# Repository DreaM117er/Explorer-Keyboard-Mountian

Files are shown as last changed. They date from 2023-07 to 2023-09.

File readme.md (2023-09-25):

# Explorer Keyboard Mountain 探索者2號（一體式）

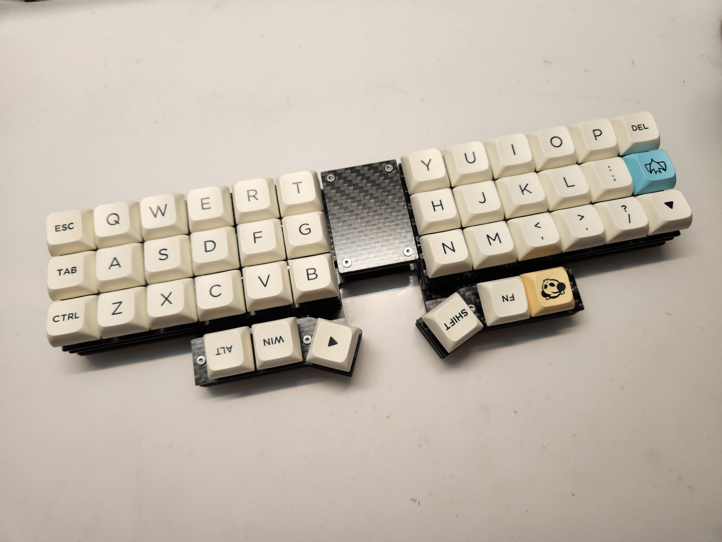
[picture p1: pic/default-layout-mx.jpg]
default-layout-mx
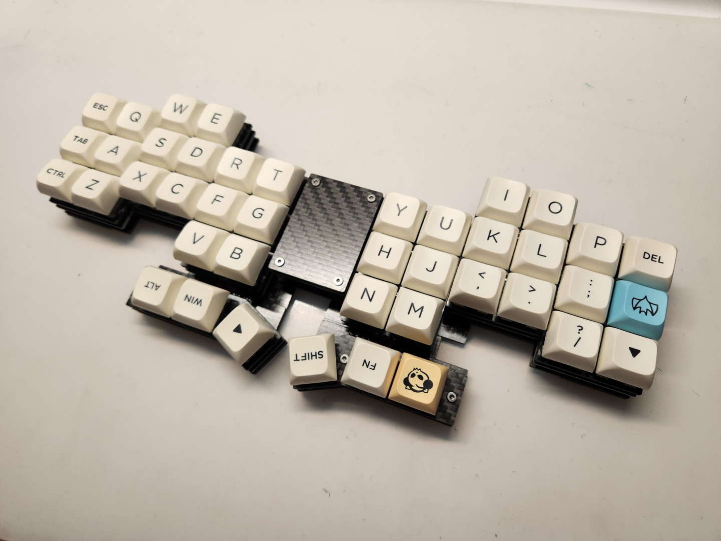
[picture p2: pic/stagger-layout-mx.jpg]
stagger-layout-mx
|||
|--|--|
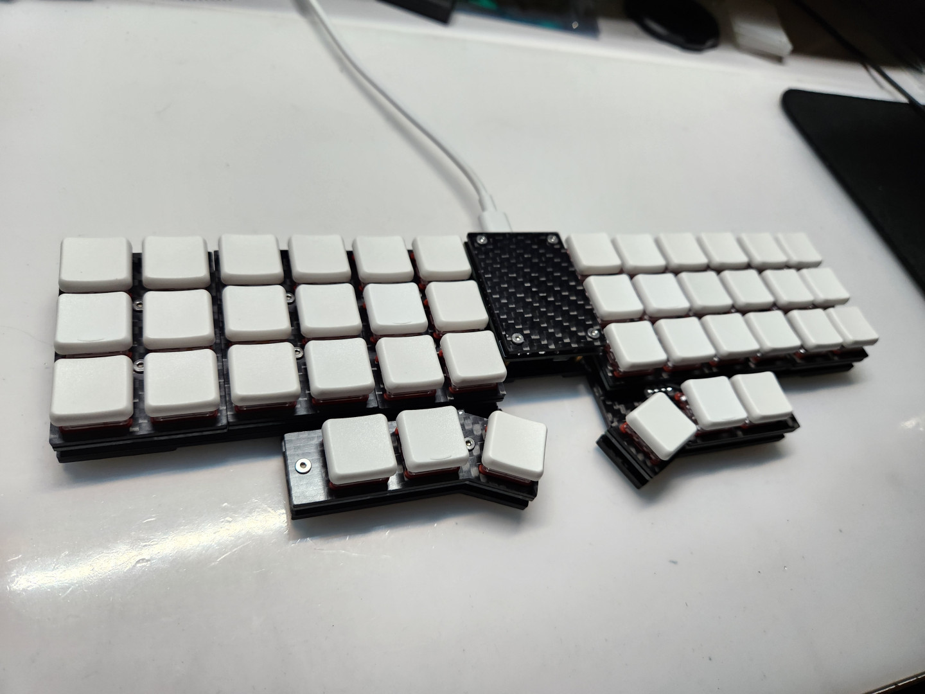
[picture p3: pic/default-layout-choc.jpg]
default-layout-choc
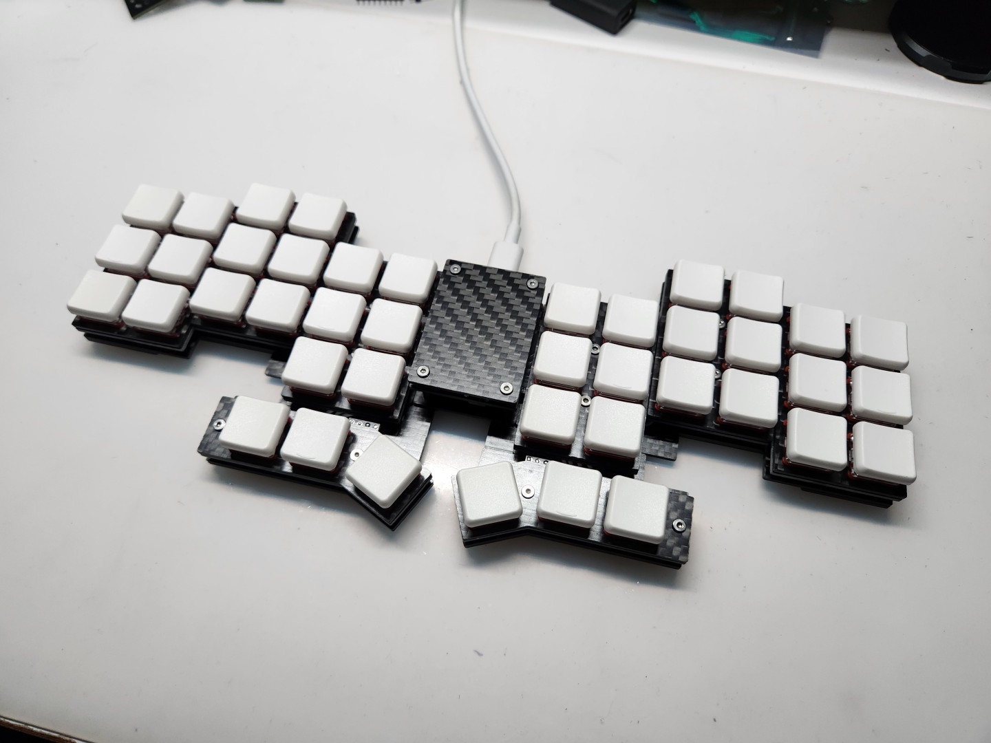
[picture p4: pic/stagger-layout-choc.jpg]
stagger-layout-choc
|||
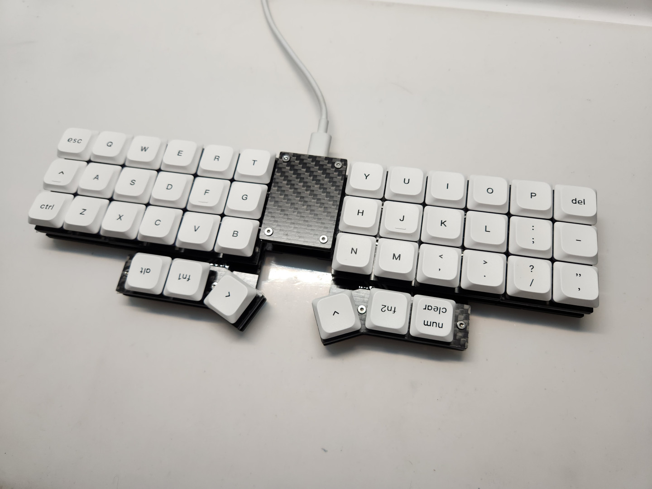
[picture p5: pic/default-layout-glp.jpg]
default-layout-glp
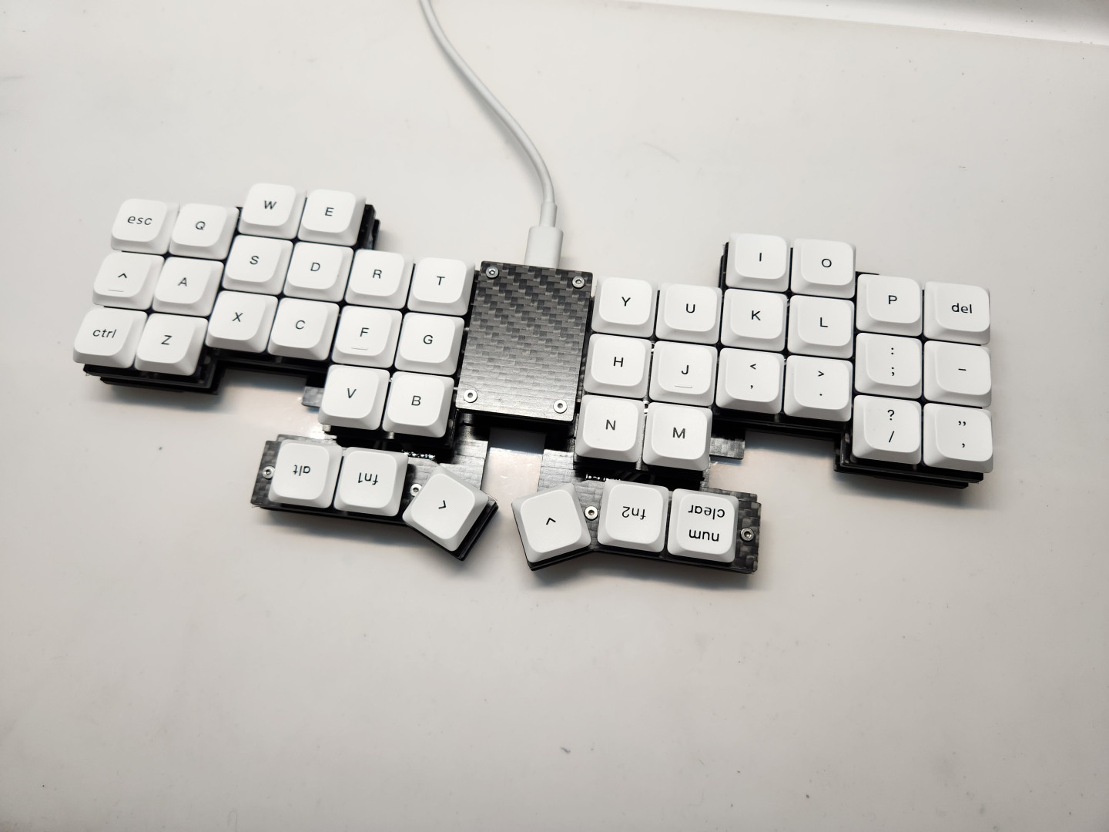
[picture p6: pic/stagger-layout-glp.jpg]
stagger-layout-glp
|||
## 開發者前言

Planck好不好用？這是我在接觸分離式鍵盤之後很多人問我的問題，我可以說它相當地好用，是第一次接觸分離式鍵盤的初心者在使用它之後也非常容易上手，且不論這把直列式鍵盤類型是不是分離式。根據Planck入門的好用程度，首先我製作了一把以Planck為雛形的直列式小鍵盤Plancklite，省去了小指及無名指最難接觸到的左下角、右下角的各3顆按鍵，再將鍵盤從中央分開來成左右兩邊、拇指區向下跟主鍵區位移3mm的設計。

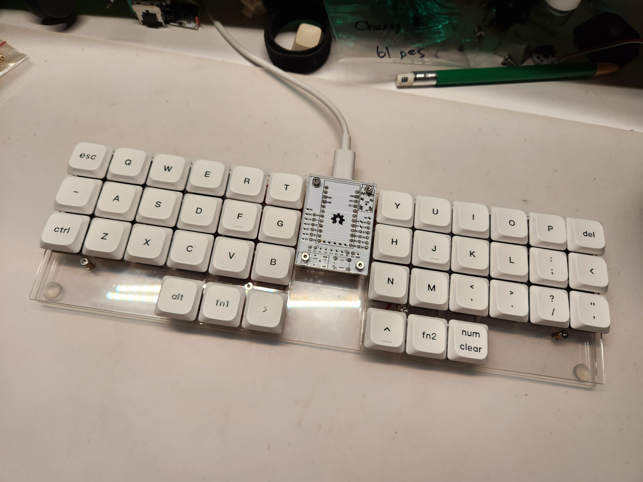
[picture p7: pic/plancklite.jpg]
plancklite


這樣去更動配列的好處其實改善了Planck鍵盤配列的幾個問題：

- 按鍵佈局太緊湊。
- 省去手指正常移動軌跡中根本按不到的按鍵。
- 保留Planck直列式鍵盤的打字手感，甚至更好。
- 可作為分離式鍵盤練習使用。

於是根據這把小鍵盤Plancklite，更進一步構想出這把可以變動配列的探索者2號。

這次的開發跟探索者1號那次不太一樣，開發、構想、設計、命名全靠我一個人，特別在這次的開發上，我特別學習了KiCAD的使用，同時運用Fusion360做鍵盤的3D結構模擬及零件的檔案輸出，能夠這樣開發出自己的鍵盤，真的相當不容易。

至於命名的部分，為什麼叫做Mountian呢？其實探索者2號的命名在1號設計出來沒多久就定下來了，原先它的目標是能夠立起來的設計，在設計過程中逐漸偏離原始構想，後來才想到這個類似七巧板的設計，但原先定下來的命名就繼續沿用了，但它現在的構造其實也蠻符合這個味道。

如果大家對這把鍵盤有興趣的話，不妨嘗試自己做看看：[組裝說明](guide.md)

分離式連結：[Half-Mountain](readme_hm.md)。

## 配列佈局

探索者2號有兩種佈局可以變更，預設佈局為Plancklite的設計，拇指區最外側旋轉25度的設計，在使用上更貼合拇指移動的按鍵軌跡。

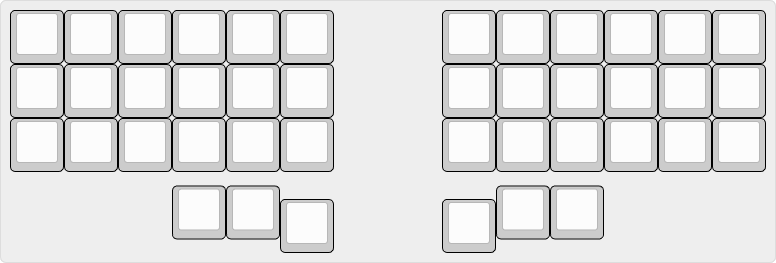
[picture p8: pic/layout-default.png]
Plancklite


在此之上，根據鍵盤結構的變化，可將Plancklite的配列變更為Stagger的配列：

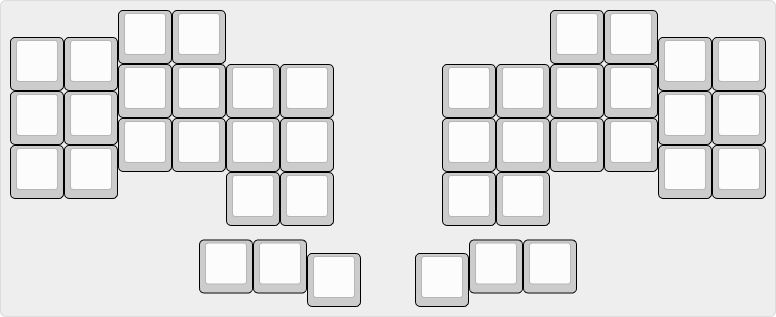
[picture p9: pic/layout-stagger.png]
mountain


## 鍵盤結構

- 根據PCB分為`M（Main）`、`A（A part）`、`B（B part）`、`T（Thumb）`單邊4個部件，合計8張PCB。
- 左右邊代號分別為：`左（L）`、`右（R）`。
- 鍵盤上下結構分為：`Plate（定位板）`、`A（上層底板）`、`B（下層底板）`。
- MCU的部分採用手拉線拓展板安裝（[Handwiring Microboard](https://github.com/DreaM117er/Handwiring-Microboard)）。
- PCB採全焊接設計，可使用`MX`、`Choc v1`、`Choc v2`、`Gateron矮軸`等4款不同腳位、不同類型的鍵軸。
- 可依據需求進行配列的變更，Plancklite及Stagger可選擇。

### PCB視圖

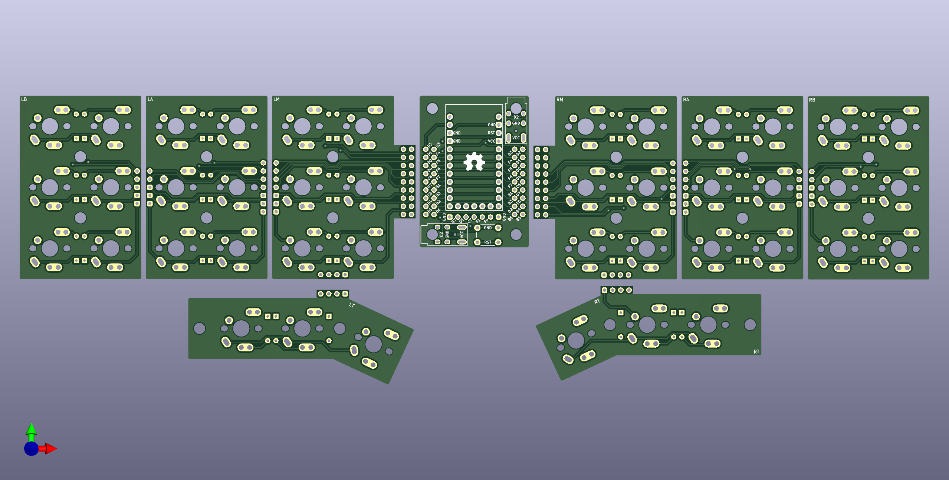
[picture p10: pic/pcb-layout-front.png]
PCB-F
|正面||
|--|--|
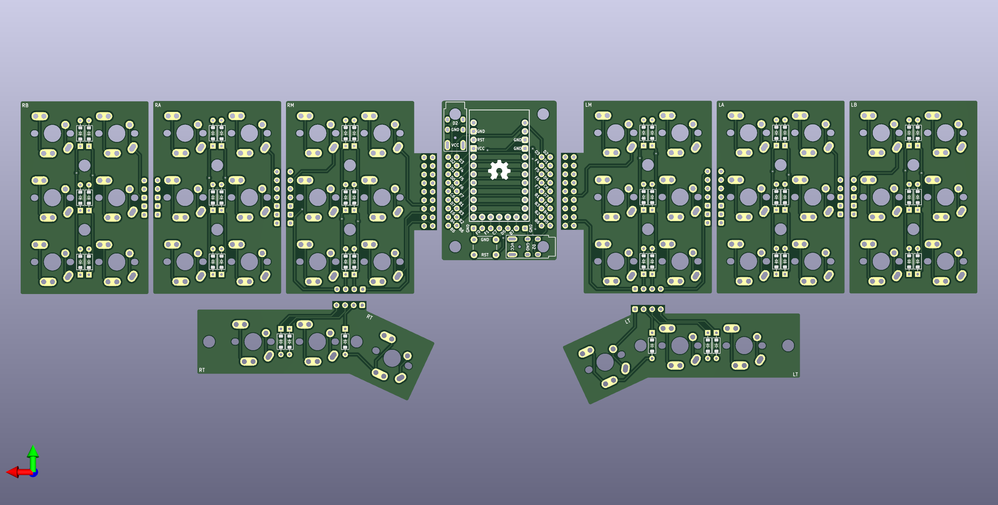
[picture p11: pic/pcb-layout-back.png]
PCB-B
|背面||

### 3D視圖

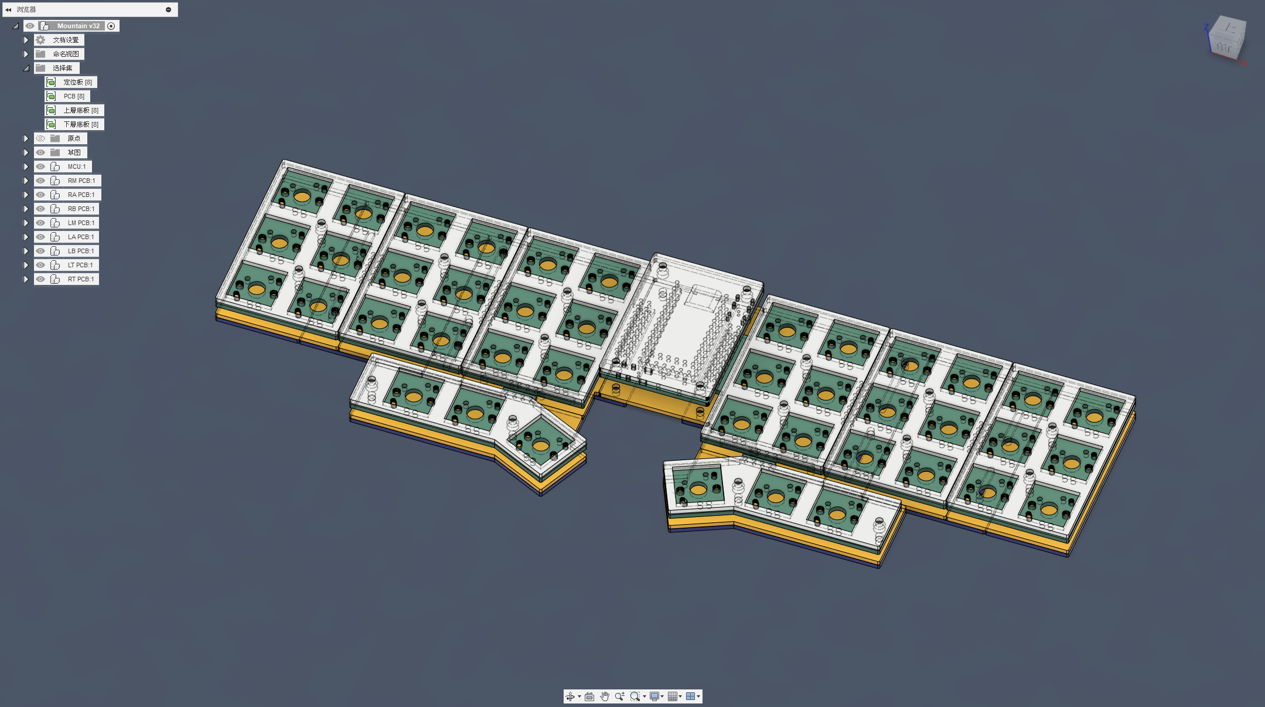
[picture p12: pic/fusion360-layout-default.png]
default
|正面||
|--|--|
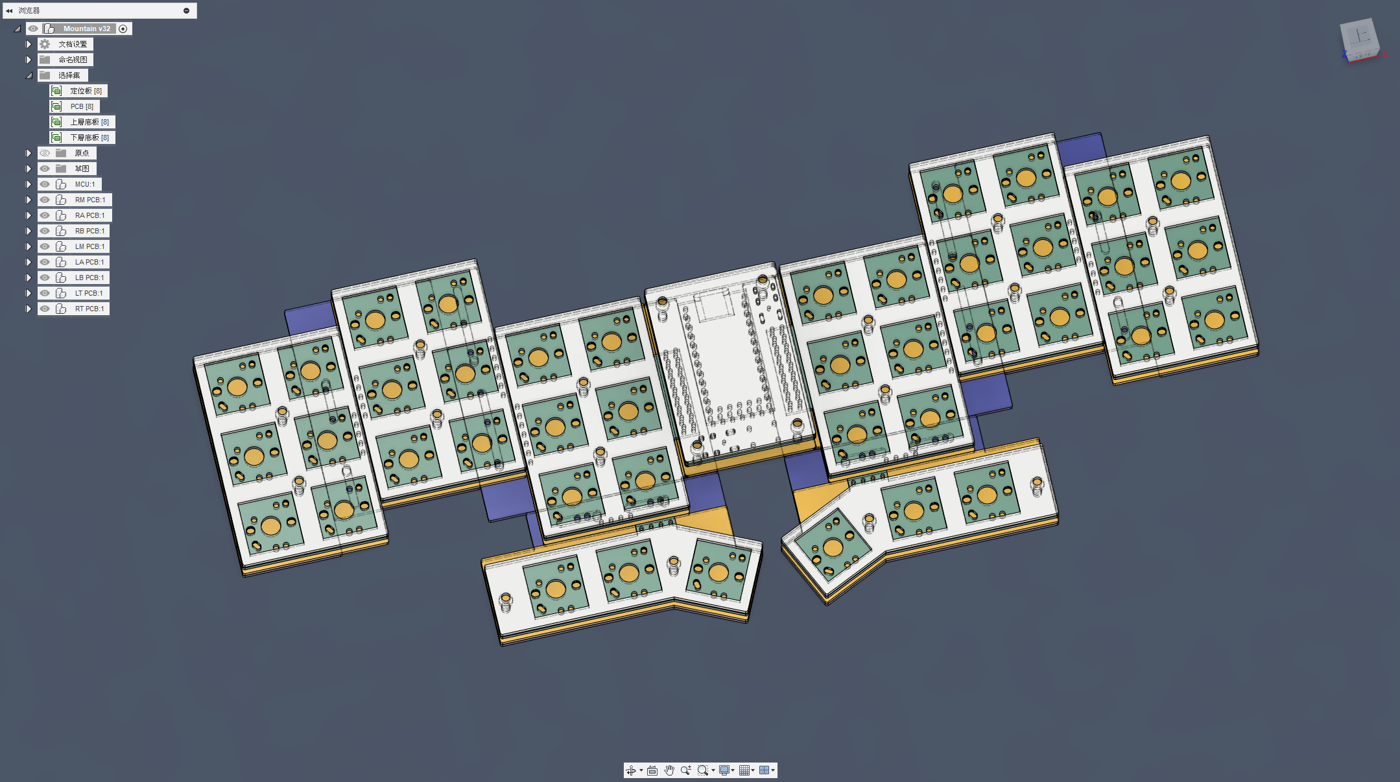
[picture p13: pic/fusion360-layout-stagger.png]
stagger
|背面||

## 參考資料及使用工具

- [凱華電子規格書](https://www.kailh.net/pages/product-datasheet)（`MX`、`Choc v1`、`Choc v2`）。
- [佳特隆電子規格書](https://www.gateron.co/products/gateron-low-profile-mechanical-switch-set)（`Gateron矮軸`）。
- [KiCAD](https://www.kicad.org/) version `7.05`。
- [Autodesk Fusion360](https://www.autodesk.com/products/fusion-360/overview?term=1-YEAR&tab=subscription)。
- [JLCPCB](https://jlcpcb.com/)。
- [鑫帆宇碳纤维用品加工店](https://shop73091441.taobao.com/?spm=a1z10.1-c-s.0.0.3530f19cYKPwZf)。
- [開發日製](log.md)。

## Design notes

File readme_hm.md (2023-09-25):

# Explorer Keyboard Half-Mountain 探索者2號（分離式）

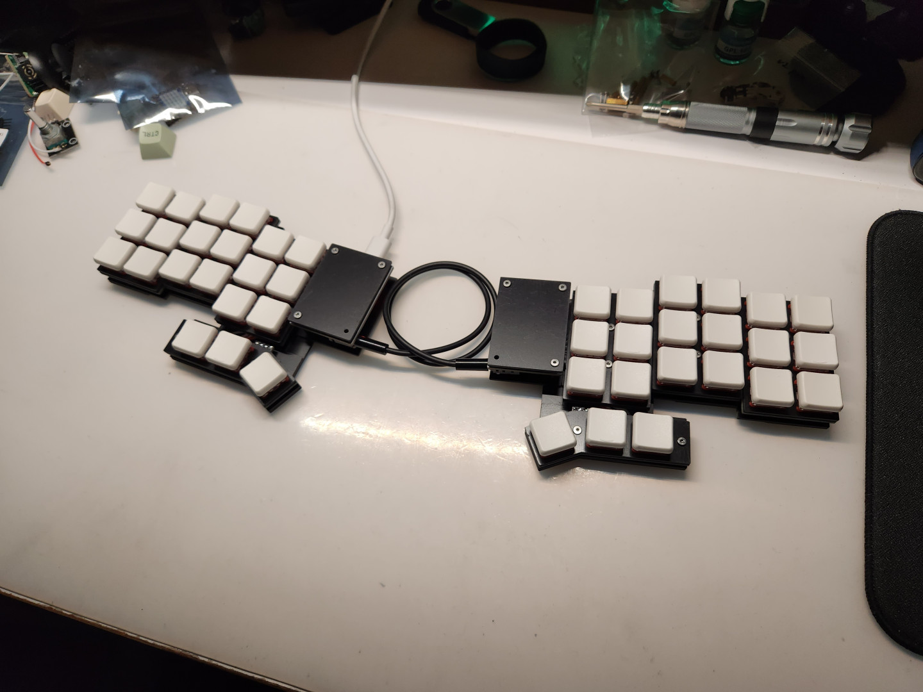
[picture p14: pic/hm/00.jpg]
Half-Mountian


## 開發者前言

探索者2號分離式版是2號本身的進階運用，使用2片的手拉線拓展板進行拓展，將一體式的探索者2號直接從中央切開來，再用分離式鍵盤常見的TRS或TRRS線做左右兩側鍵盤的連接，來滿足不喜歡一體式鍵盤使用者的需求。

由於是分離式版的探索者2號是將鍵盤從中央切開來的原因，很直接地將鍵盤稱之為`半山（Half-Mountain）`。

## 組裝說明

Half-Mountain是在Mountain的基礎上做延伸的分離式鍵盤，詳見以下材料不同處：

|項目|數量|備註|
| -- | -- | -- |
|[手拉線拓展板](https://github.com/DreaM117er/Handwiring-Microboard)（`Handwiring Microboard`）|2片|-|
|`Pro Micro` `5V16M`|2片|同腳位MCU都可|
|MCU保護板（`cover`）|4片|上下及左右|
|`TRRS座`|2個|-|
|`2pin` 輕觸開關|2個||

- 其餘材料都和[Mountain](https://github.com/DreaM117er/Explorer-Keyboard-Mountian/blob/main/guide.md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)一致。

## 組裝步驟

- 請按照步驟先將2片手拉線拓展版安裝完畢：[請點這裡](https://github.com/DreaM117er/Handwiring-Microboard)。

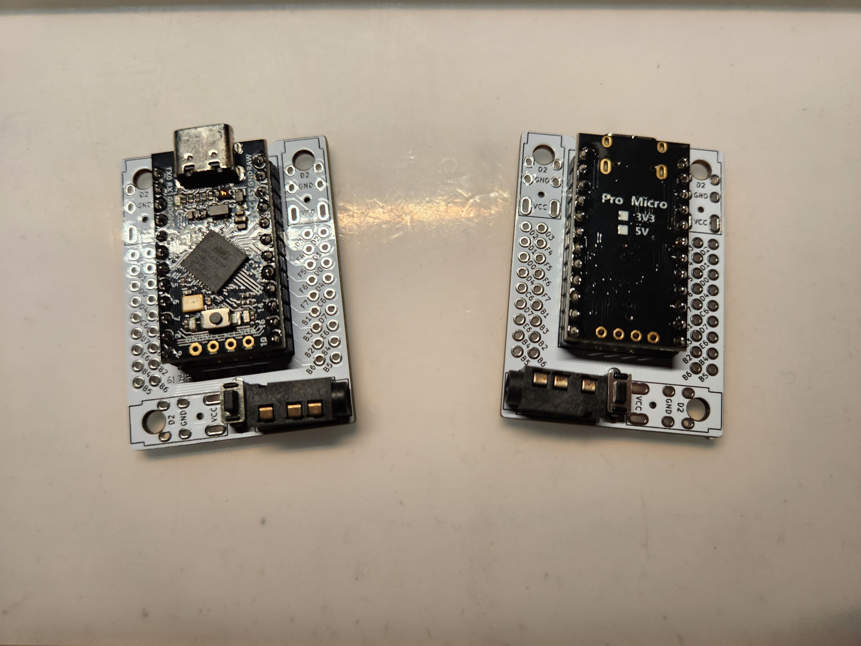
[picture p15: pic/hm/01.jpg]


- 接著將Half-Mountain的韌體燒錄進左右手MCU中。（詳見[`Release`](https://github.com/DreaM117er/Explorer-Keyboard-Mountian/releases)）

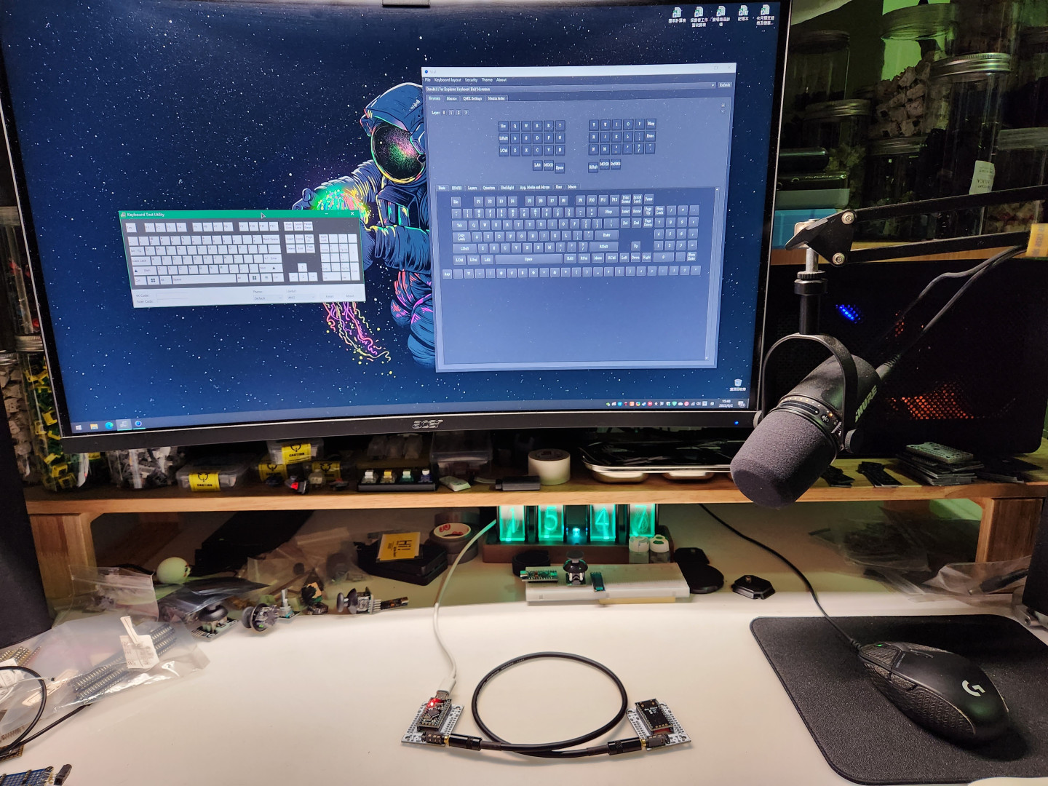
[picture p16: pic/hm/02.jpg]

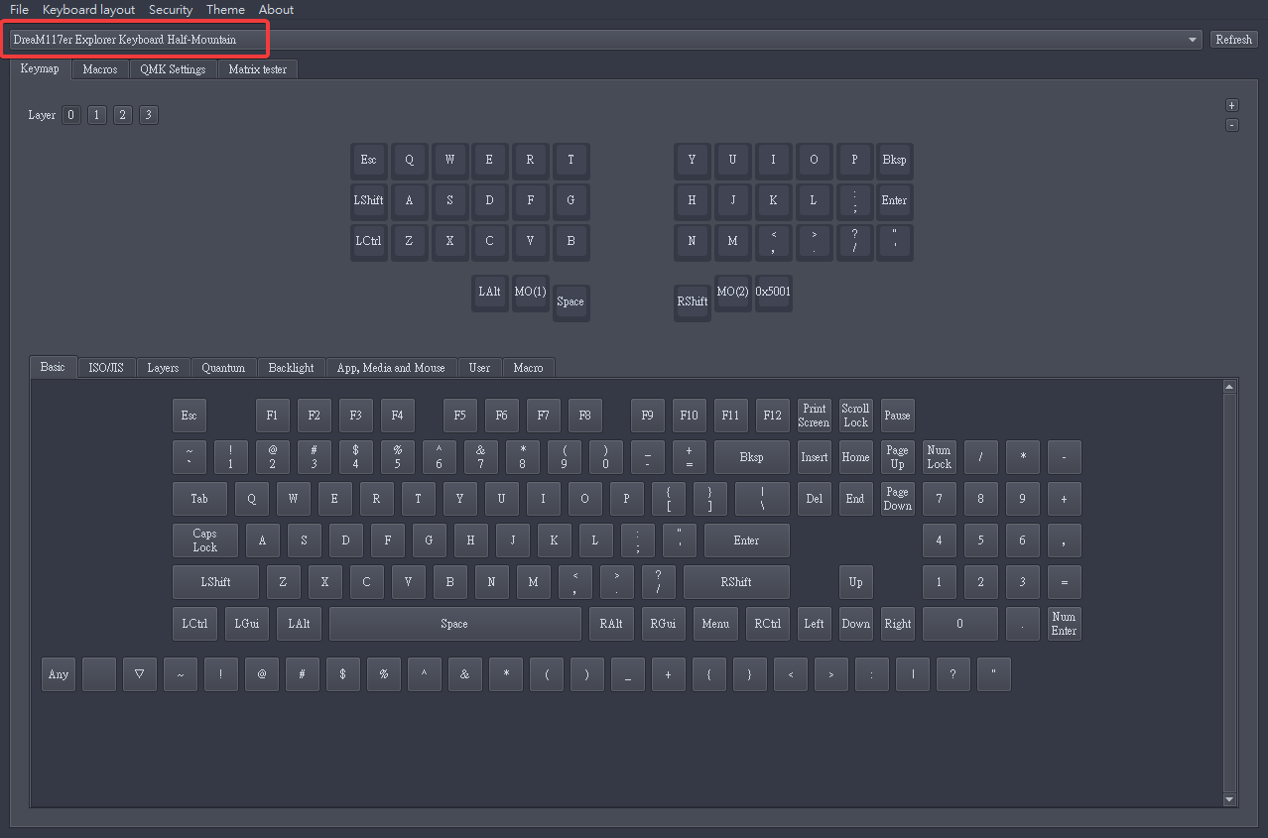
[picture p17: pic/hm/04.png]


- 接著將Mountian的左右邊外殼及鍵盤依序完成：[請點這裡](guide.md)。

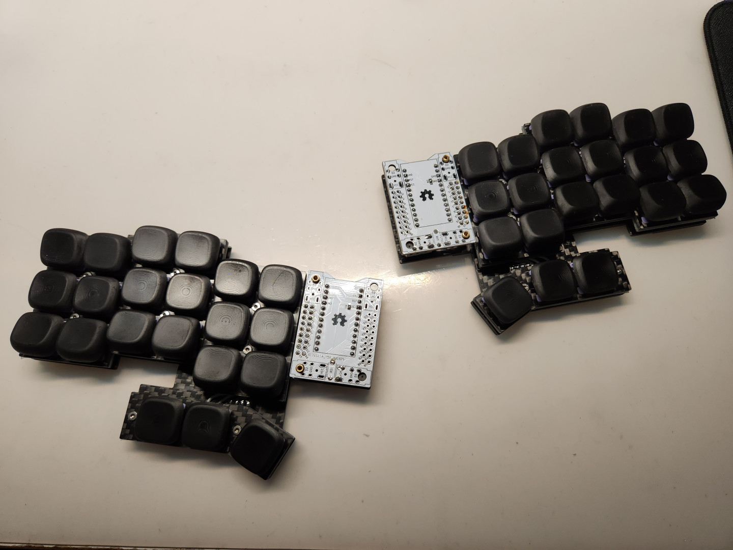
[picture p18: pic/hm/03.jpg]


- 將左右手鍵盤各安裝一片手拉線拓展板後，將外殼安裝上去就完成了。

Half-Mountian

## 注意事項

> **Warning**
>
> 分離式版的探索者2號會犧牲左右邊鍵盤手拉線拓展板的1個螺絲鎖點，不會影響使用。

> **Warning**
>
> 安裝TRRS座時留意方向性及螺絲鎖點，與左右鍵盤本體至少要有`2個鎖點`。

> **Warning**
>
> 鍵盤預設為`左側為主`鍵盤，`右側為輔`；有特殊需求請至`Fork/vial-qmk`詳見韌體代碼：[Explorerkb](https://github.com/DreaM117er/vial-qmk/tree/vial/keyboards/explorerkb)

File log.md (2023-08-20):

# 開發日誌

## 開發歷史

- 22.07.21 完成簡易版Plancklite。
- 22.07.22 完成探索者2號的3D結構。
- 22.07.23 最終修正修正探索者2號PCB邊緣。
- 22.07.24 向JLCPCB請求製作PCB訂單。
- 22.07.26 向鑫帆宇碳纤维用品加工店定製碳纖維材質外殼。
- 22.07.26 探索者2號的Github頁面正式建立。
- 22.08.01 PCB第一階段測試，RM部分有瑕疵問題再送洗。
- 22.08.17 碳纖維外殼到貨，開始組裝測試鍵盤。
- 22.08.18 Choc v1版完成，Debug測試未過。
- 22.08.19 MX版完成，測試通過。
- 22.08.19 第一階段上傳照片到reddit上分享。
- 22.08.20 Gateron Low Profile矮軸版完成，測試通過。
- 22.08.20 Building Guide組裝說明完成。

## 開發歷程

為了自己製作鍵盤，2023年年初我學習了3D繪圖，使用Fusion360製作了我的第一把鍵盤探索者1號，同時也將探索者系列這個特別的計劃定型，往後這個系列會出產一些顛覆想像的機械鍵盤。當然一開始也有提到，探索者2號在1號設計出來沒多久就已經將名稱定下，希望這把鍵盤能夠以立起來擺放為出發點，做一個擁有探索者精神，也就是超高自由度的機械鍵盤。

不料整個過程往往不會按照最初的意思走，最初還沒有正式開始學習KiCAD怎麼使用時，我都是以手拉線方式為基底製作鍵盤的3D模型，但製作出來的成果都不滿意，於是將2號的開發暫時放一邊，轉而開始開發探索者的其他系列。直到將KiCAD學習差不多後，將手拉線拓展板製作（[Handwiring Microboard](https://github.com/DreaM117er/Handwiring-Microboard)）出來，才正式將鍵盤的基礎定型，因為這個拓展板能夠更方便地製作鍵盤，其最大的可能性是能製作矩陣大小`17x6`的機械鍵盤，也就是`80% TKL`的大小。

開發拓展板到`v3`版本時，我發現手邊累積的單格電路板、瑕疵拓展板有一定程度的量，這樣想想也不是什麼辦法，於是將Fusion360打開，以Planck為基礎設計了一個簡單的模型，就這樣將模型交給定製壓克力及碳纖維的廠家定製，製作出來的就是Plancklite，我將它稱作試作型系列。

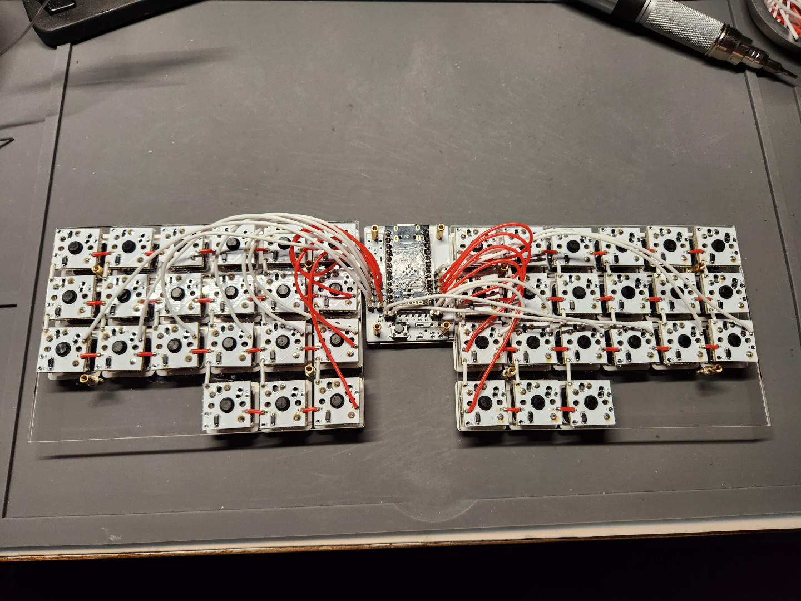
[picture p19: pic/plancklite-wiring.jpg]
plancklite

plancklite

7月22日當天在臺灣高雄衛武營舉辦[鍵盤好貴](https://expensivekb.com/zh-hant/collections/keyboard)的鍵盤線下交流聚會，我將這把鍵盤帶過去做展示，與一般客製化鍵盤不同的是，我喜歡運用手邊的材料自己製作鍵盤，當天也和使用分離式鍵盤的使用者進行交流，相當地愉快。聚會當天返程回家之後開始使用Plancklite開始著手製作探索者2號的PCB及外殼結構的設計。

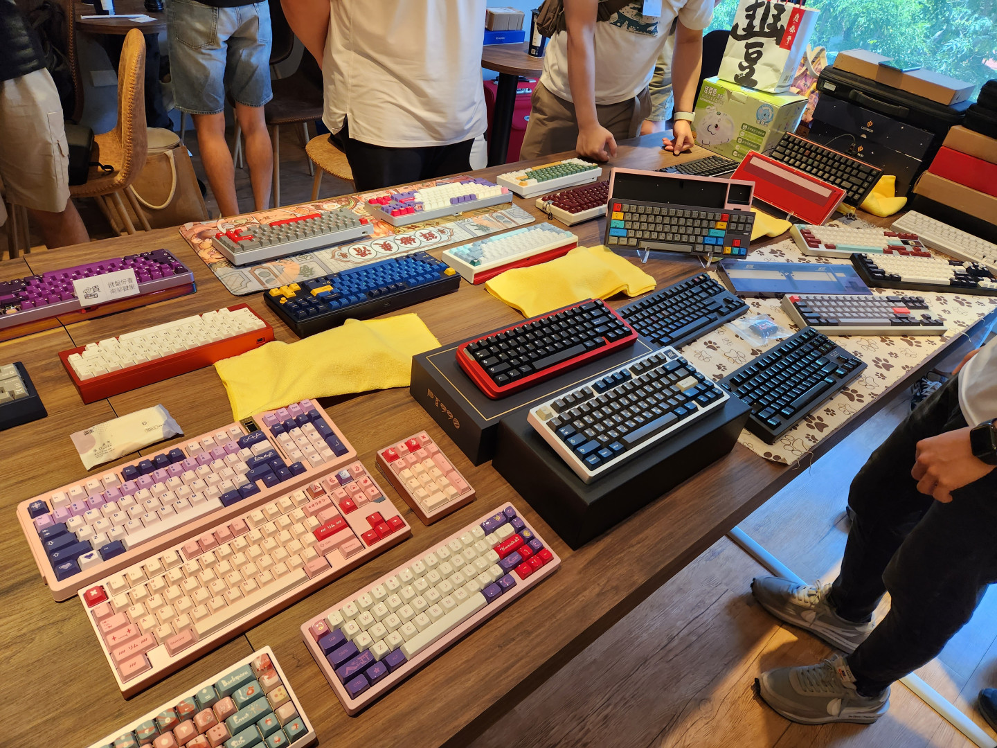
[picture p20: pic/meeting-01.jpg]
meeting

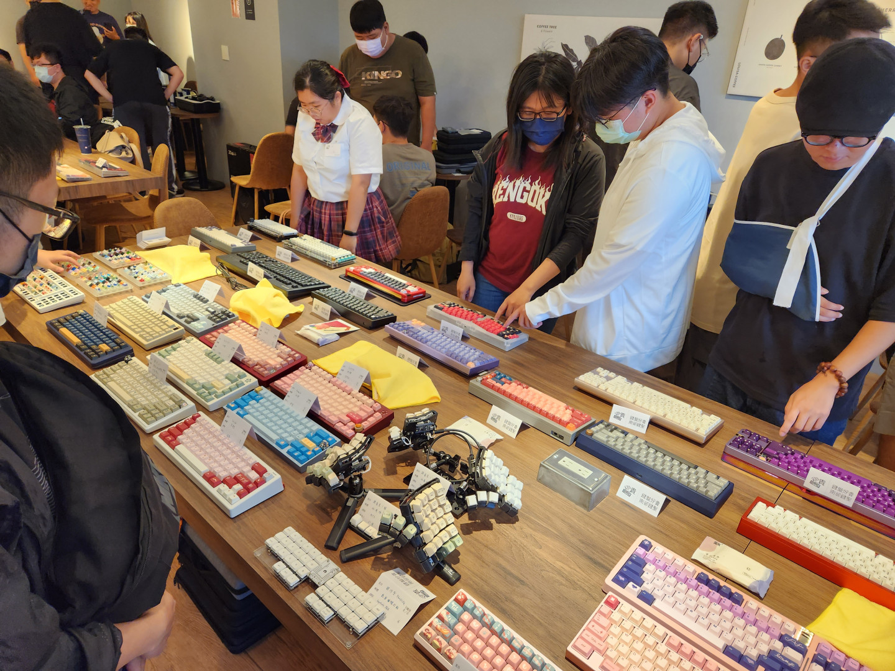
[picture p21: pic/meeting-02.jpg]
meeting


新版的手拉線拓展板捨棄了當初以分離式鍵盤為出發點而將針腳拓展到左右邊，而是依據使用的主控板上可用做訊號編程的18個針腳直接拓展到板子的左右2側做對稱拓展，這樣有一個好處，不管開發板要定位在鍵盤按鍵的任何一側都非常容易安裝。

新設計的PCB搭配`v4`版本的拓展板後，整體的結構就已經定型，於是花了點時間模擬鍵盤要如何做出可以變更結構的固定方式，最後想到的就是使用雙層的底板做結構變化。

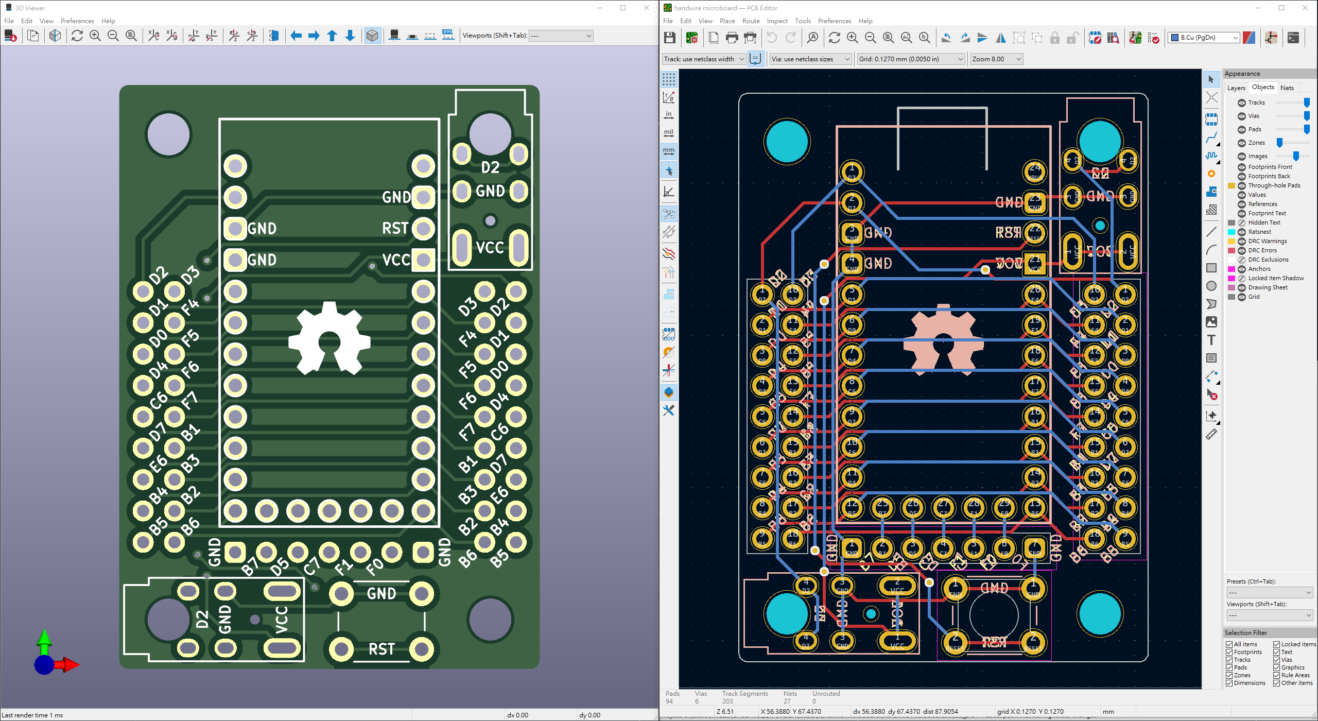
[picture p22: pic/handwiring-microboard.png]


大家試想一下，`3.2mm`有多厚？而這個厚度很厚嗎？

雙層結構大致上都圍繞這兩個問題在轉，雙層的底板乍看下相當的厚實，但每層的厚度僅僅只有一般電路板`1.6mm`厚度，這個厚度堆疊起來實際上真的沒有這麼厚，Plancklite這把小鍵盤的底板加上腳墊的厚度其實也有`4mm`左右，這也是為什麼我可以這麼放心地使用雙層結構的原因。

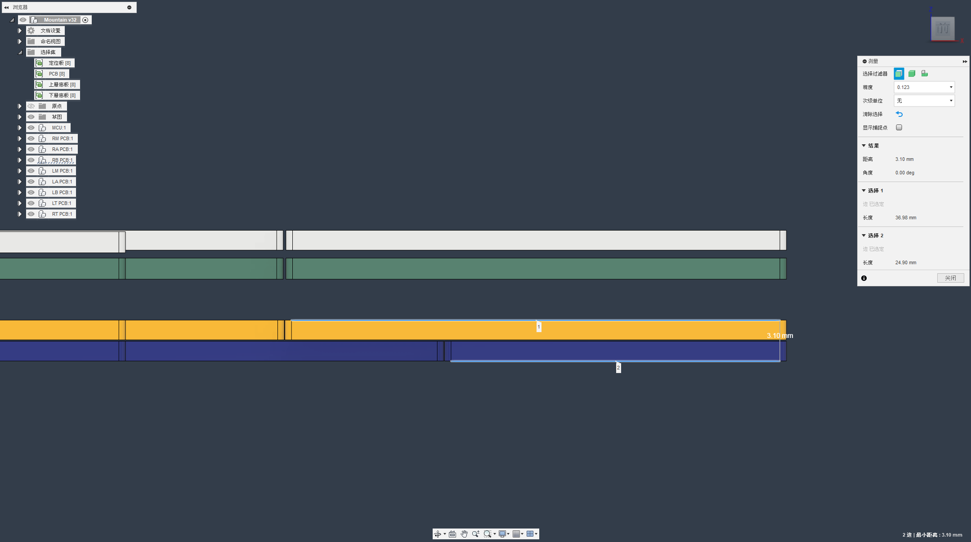
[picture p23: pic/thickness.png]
thinkness


再來是滑軌結構，這是參照另一把鍵盤[Dactyl Chimera](https://github.com/WolfIcefang/dactyl-chimera-keyboard)，為了定住鍵盤的雙層結構，我將螺母定位成滑軌移動元件，開孔設計在上層底板上，下層底板用於將鍵盤配列整個固定住不要亂滑動，中央螺絲用於固定2x6的定位板。

也因為這個結構，導致使用的底板材質需要一定程度的韌性及硬度，這也是為什麼推薦使用`FR4（玻璃纖維）`及`碳纖維`去製作的原因，當然如果使用3D列印的話，成品如果硬度不會讓鍵盤底板在密合時有很明顯變形的話，那也可以作為替代。

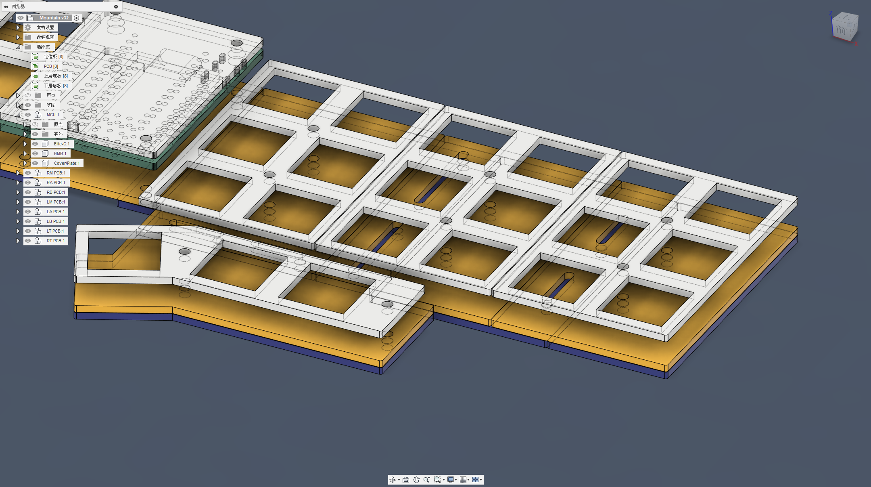
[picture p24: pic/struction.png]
struction


簡單來說，這把鍵盤其實能夠寫的東西並不是很多，最難的地方就在你要怎麼將鍵盤的自由度在有限的空間展現出來，並且能夠在這個基礎上正常地讓使用者能夠好好使用。探索者系列不僅僅是將自由度帶給了你，如果能夠讓你就此愛上鍵盤的話，那麼我的目的就已經達成了。

謝謝大家能夠看到這邊，希望各位都是喜歡鍵盤的鍵盤人，那麼我們下一把鍵盤再見。

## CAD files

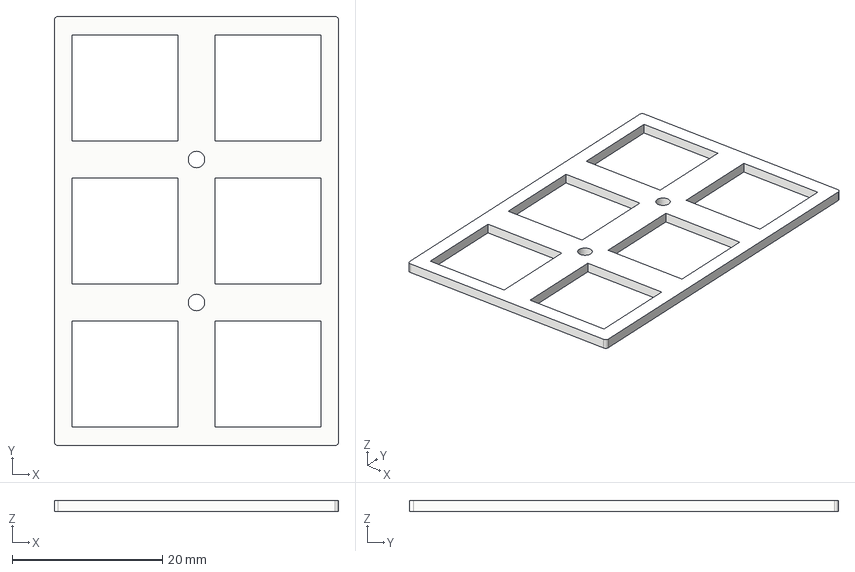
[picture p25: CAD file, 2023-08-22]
files/case/main-plate.step
37.9 x 57.2 x 1.50 mm

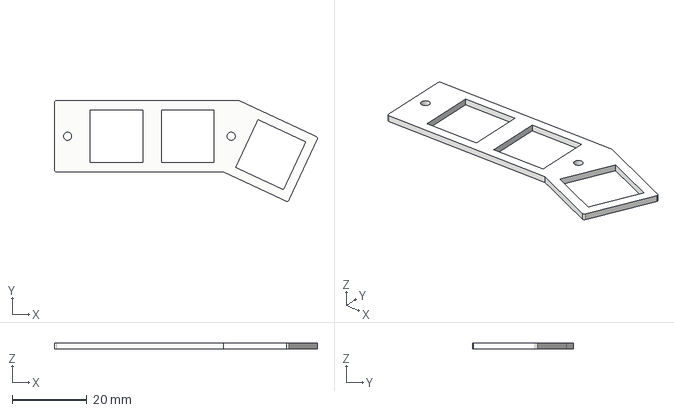
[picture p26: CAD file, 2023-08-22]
files/case/thumb-plate.step
70.3 x 26.9 x 1.50 mm

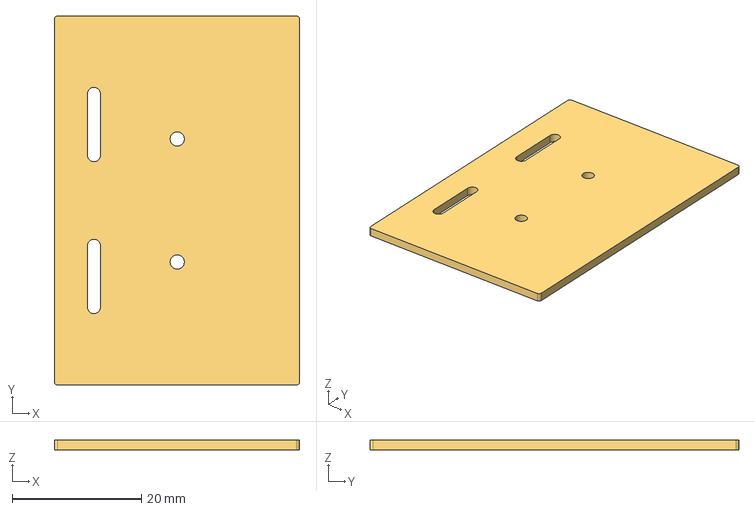
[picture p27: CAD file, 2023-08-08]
files/case/BA.step
38.0 x 57.2 x 1.50 mm

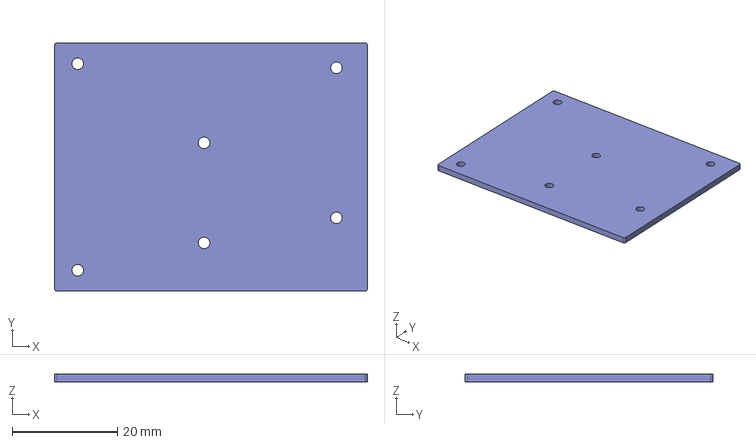
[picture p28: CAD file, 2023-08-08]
files/case/MB.step
59.6 x 47.3 x 1.50 mm

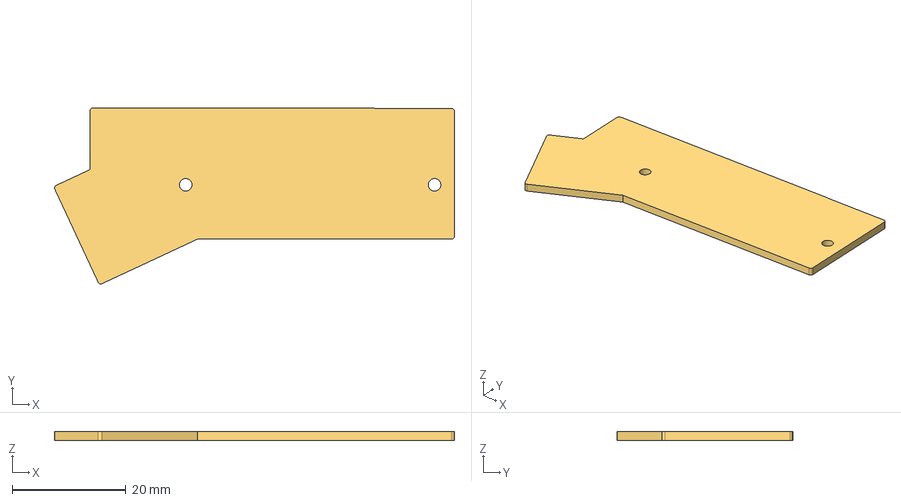
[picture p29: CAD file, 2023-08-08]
files/case/TA.step
70.3 x 30.9 x 1.50 mm

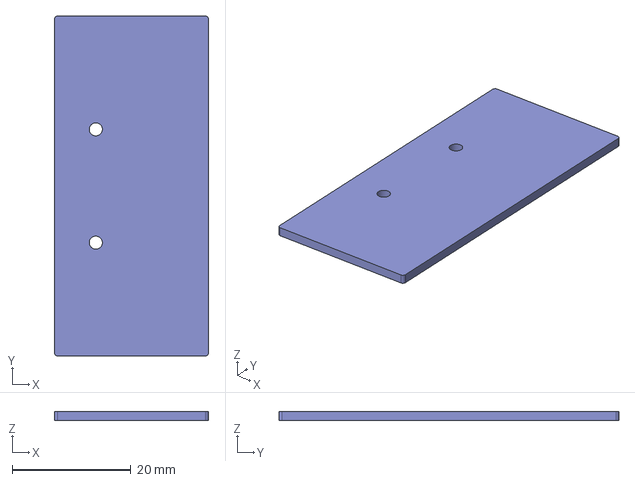
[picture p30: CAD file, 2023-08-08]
files/case/BB.step
25.9 x 57.2 x 1.50 mm

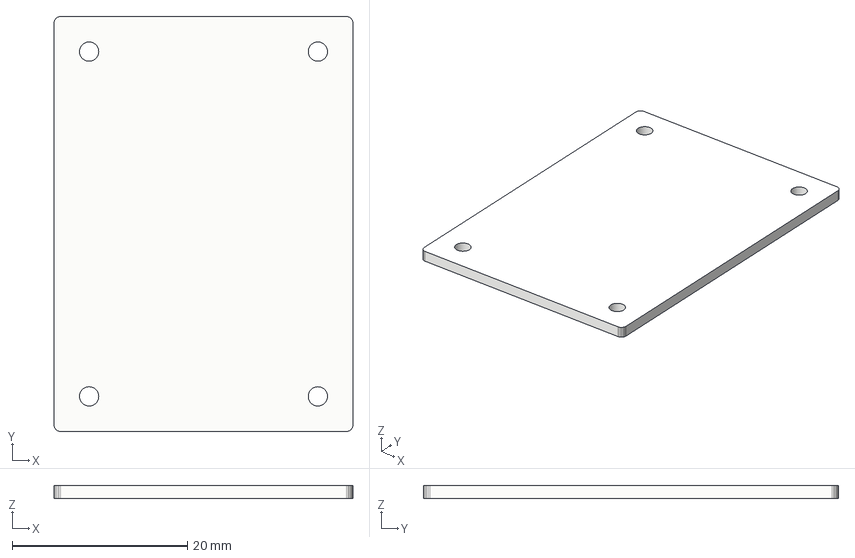
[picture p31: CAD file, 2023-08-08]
files/case/cover.step
34.1 x 47.3 x 1.50 mm

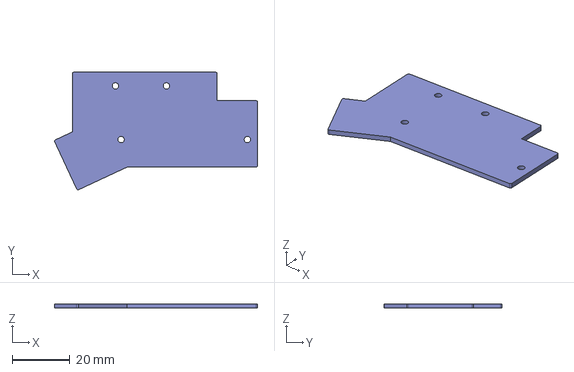
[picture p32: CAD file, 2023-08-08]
files/case/TB.step
70.3 x 40.7 x 1.50 mm

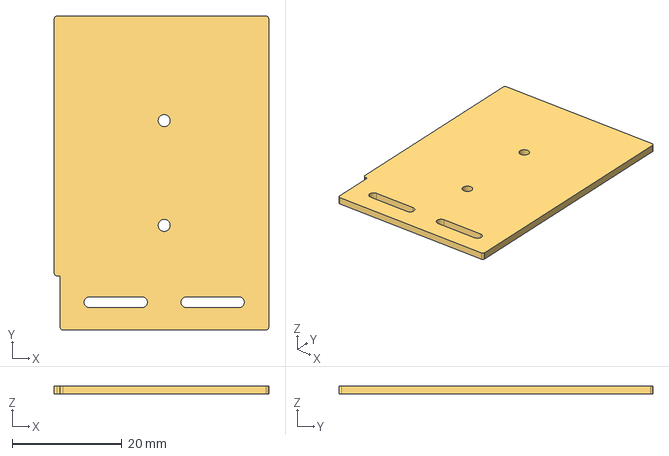
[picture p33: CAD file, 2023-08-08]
files/case/MA.step
39.0 x 57.2 x 1.50 mm

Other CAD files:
files/case/AA.step
files/case/AB.step

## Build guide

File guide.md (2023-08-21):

# 組裝說明

## （一）材料準備

### A、共通部分

|項目|數量|備註|
| -- | -- | -- |
|PCB電路板（`PCBs`）|合計8片|-|
|[手拉線拓展板](https://github.com/DreaM117er/Handwiring-Microboard)（`Handwiring Microboard`）|1片|-|
|`Pro Micro` `5V16M`|1片|同腳位MCU都可|
|`1N4148`|42粒|支援`THT`、`SMD`，選擇其中一種版本即可|
|`6mm` `H4.3mm` 輕觸開關 |1個|-|
|主定位板（`main-plate`）|6片|-|
|拇指定位板（`thumb-plate`）|2片|左右通用|
|上層底板（`MA`、`AA`、`BA`、`TA`）|各2片|4組，合計8片，左右通用|
|下層底板（`MB`、`AB`、`BB`、`TB`）|各2片|4組，合計8片，左右通用|
|MCU保護板（`cover`）|2片|上下安裝|
|`ø6mm` `H1.5mm` 矽膠自黏腳貼|-|-|
|`M2 x 4mm` 扁頭螺絲|16個|-|
|`M2 x 5mm` 扁頭螺絲|24個|-|
|`14mm` 雙通銅柱|4個|-|
|`2.54mm間距` 公母圓排針|`12pin`、`9pin`、`5pin`|-|
|`28 AWG` 矽膠線|-|-|
|`M2` 六角螺母|12個|-|
|外徑`4mm`、內徑`2mm` 橡膠圈|12個|-|
|`M2` 防滑墊片|12個|-|
|`M2 x 6mm` 扁頭螺絲|12個|-|

### B、Choc矮軸

|項目|數量|備註|
| -- | -- | -- |
|`7mm` 雙通銅柱|12個|主鍵區用|
|`5mm` 雙通銅柱|4個|拇指區|
|鍵軸|42個|`Choc v1`、`Choc v2`、`Gateron矮軸`|

### C、MX軸

|項目|數量|備註|
| -- | -- | -- |
|`10mm` 雙通銅柱|12個|主鍵區用|
|`7mm` 雙通銅柱|4個|拇指區|
|鍵軸|42個|`MX`規格|

## （二）電路板檔案

### A、左手PCB

|部件|正面（Front Side）|背面（Back Side）|
| -- | -- | -- |
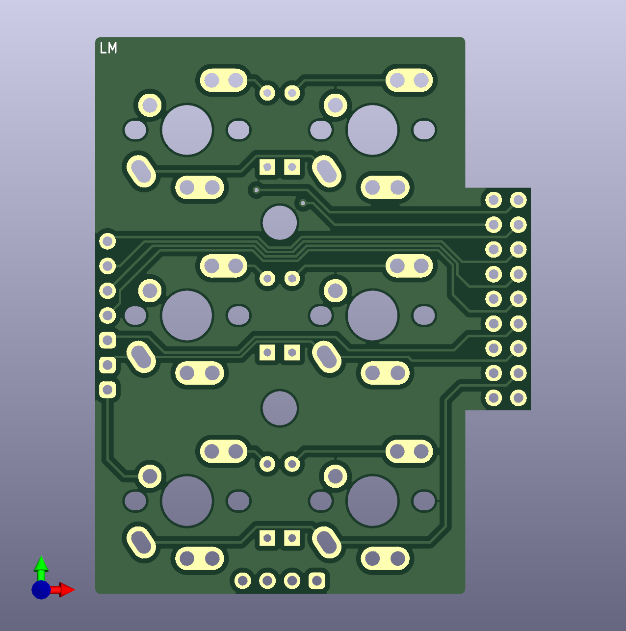
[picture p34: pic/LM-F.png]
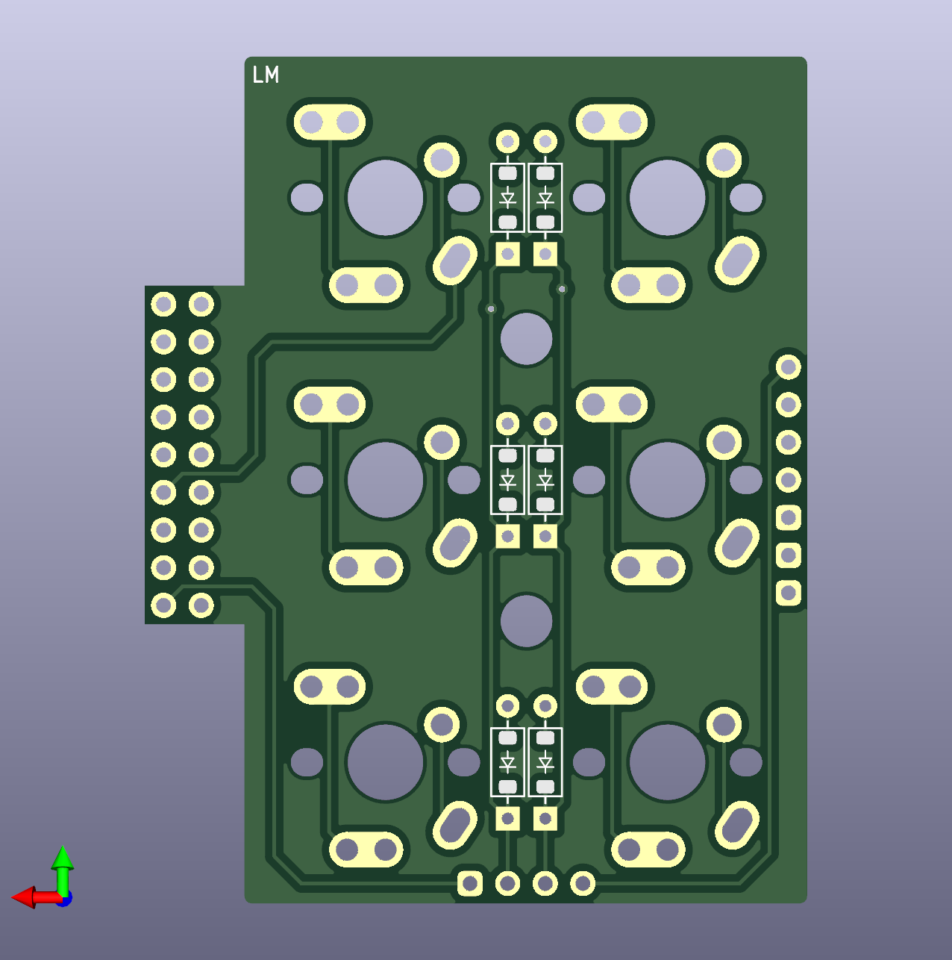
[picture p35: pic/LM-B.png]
|Main|||
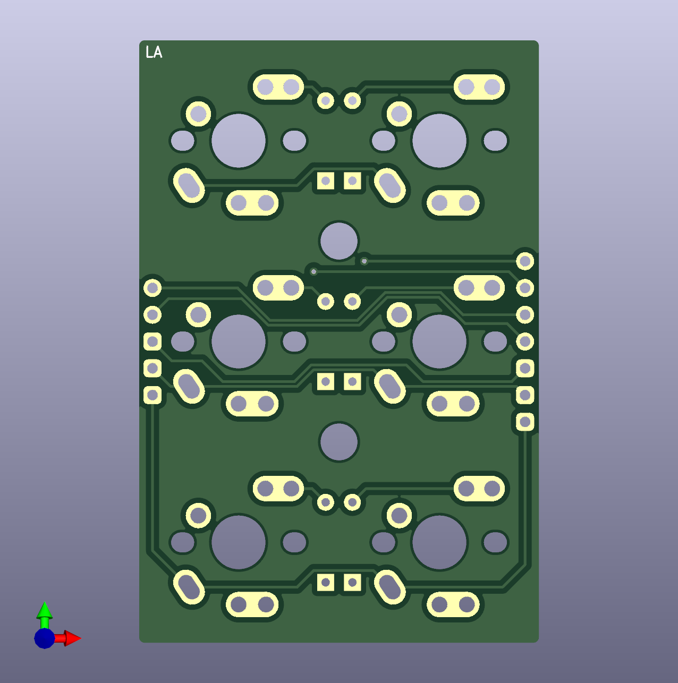
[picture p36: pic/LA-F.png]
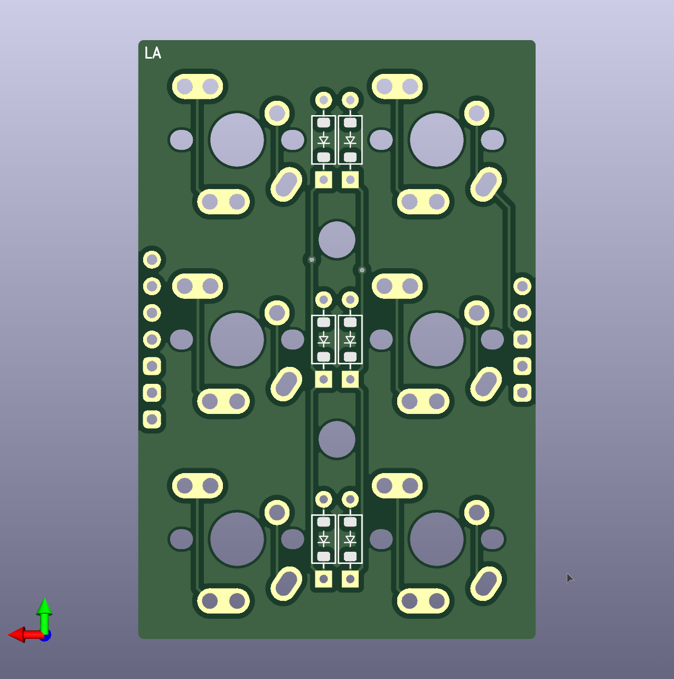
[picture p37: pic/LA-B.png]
|A part|||
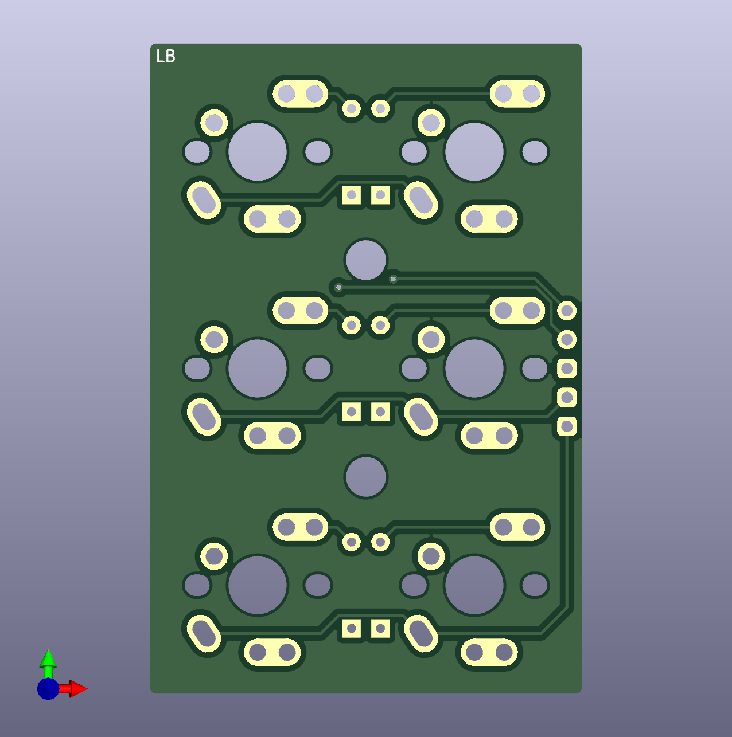
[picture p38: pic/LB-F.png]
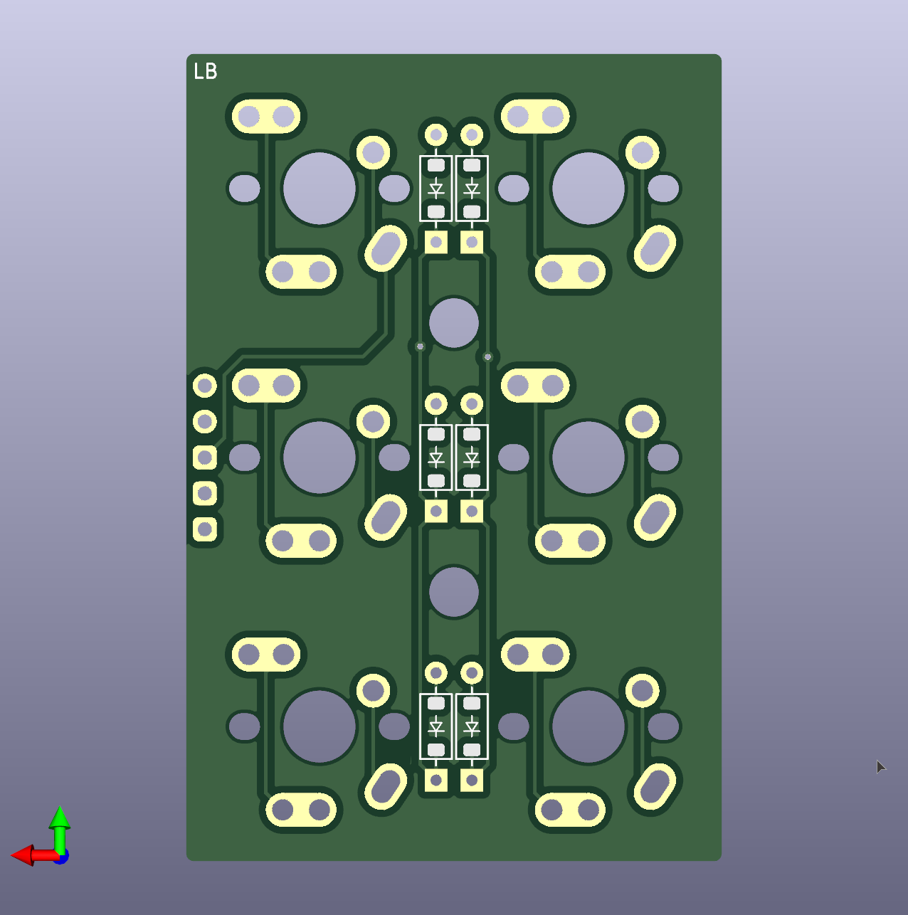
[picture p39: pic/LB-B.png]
|B part|||
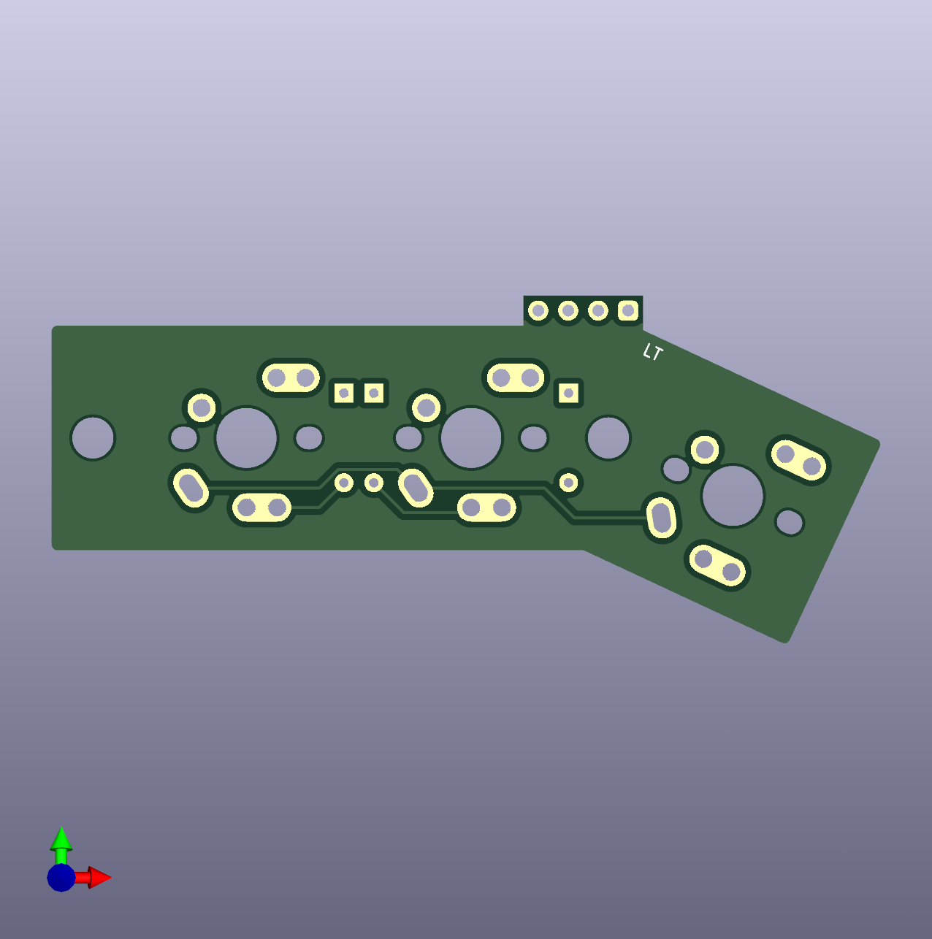
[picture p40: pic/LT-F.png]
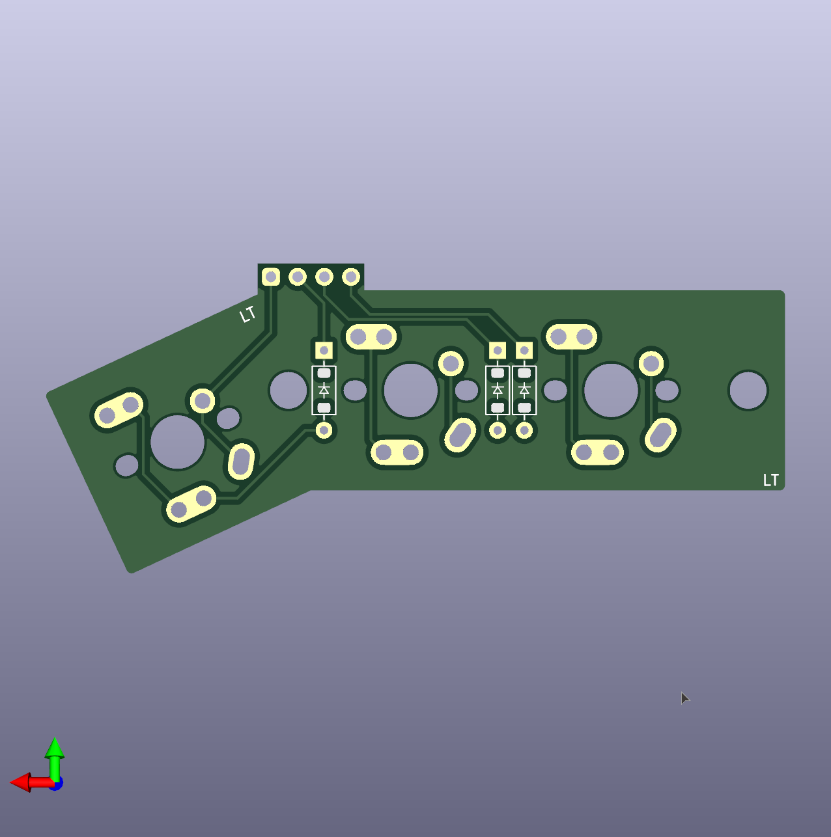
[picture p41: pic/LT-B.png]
|Thumb|||

### B、右手PCB

|部件|正面（Front Side）|背面（Back Side）|
| -- | -- | -- |
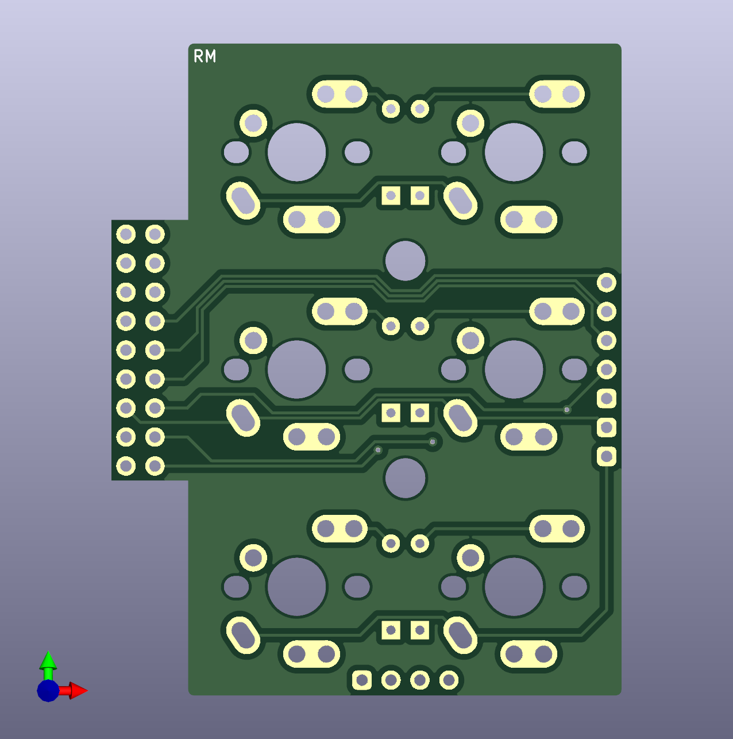
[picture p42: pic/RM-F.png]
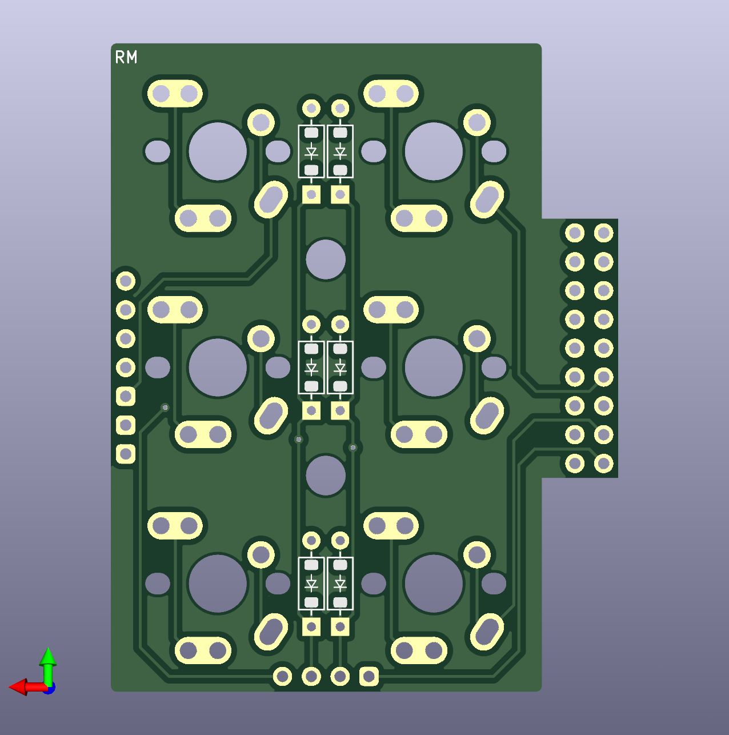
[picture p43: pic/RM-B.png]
|Main|||
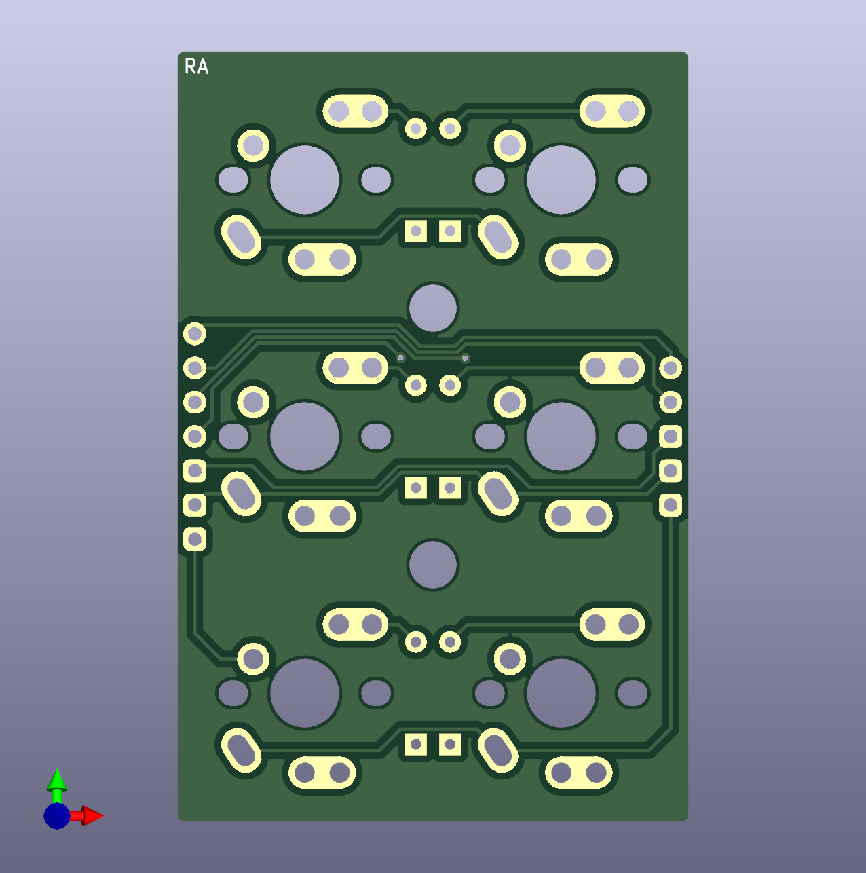
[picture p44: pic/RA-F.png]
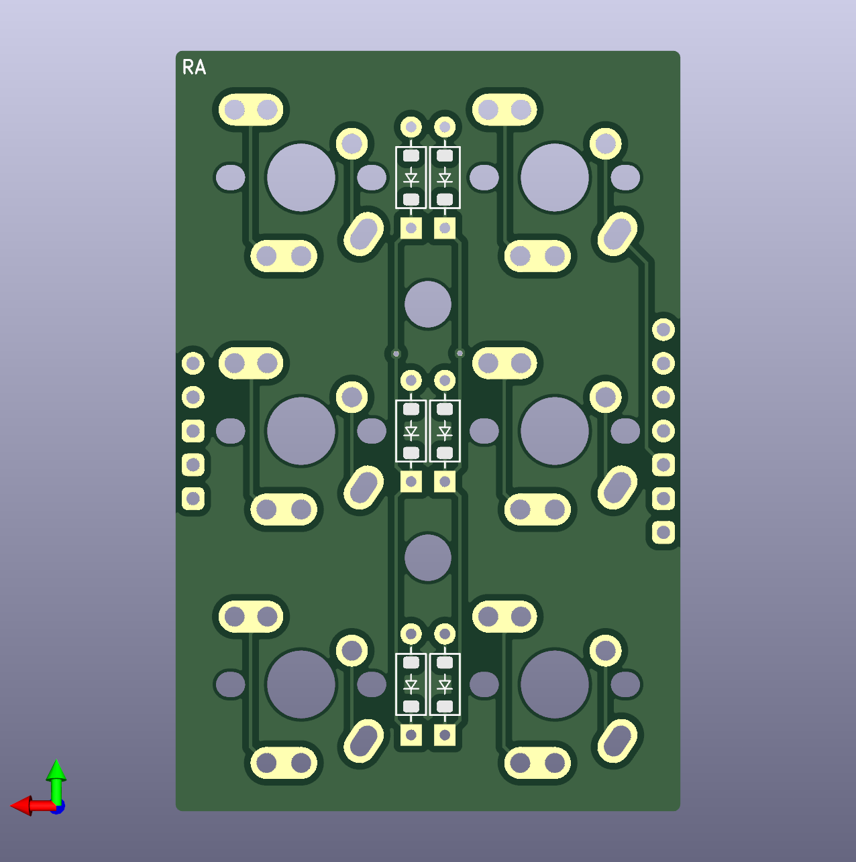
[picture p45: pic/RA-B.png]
|A part|||
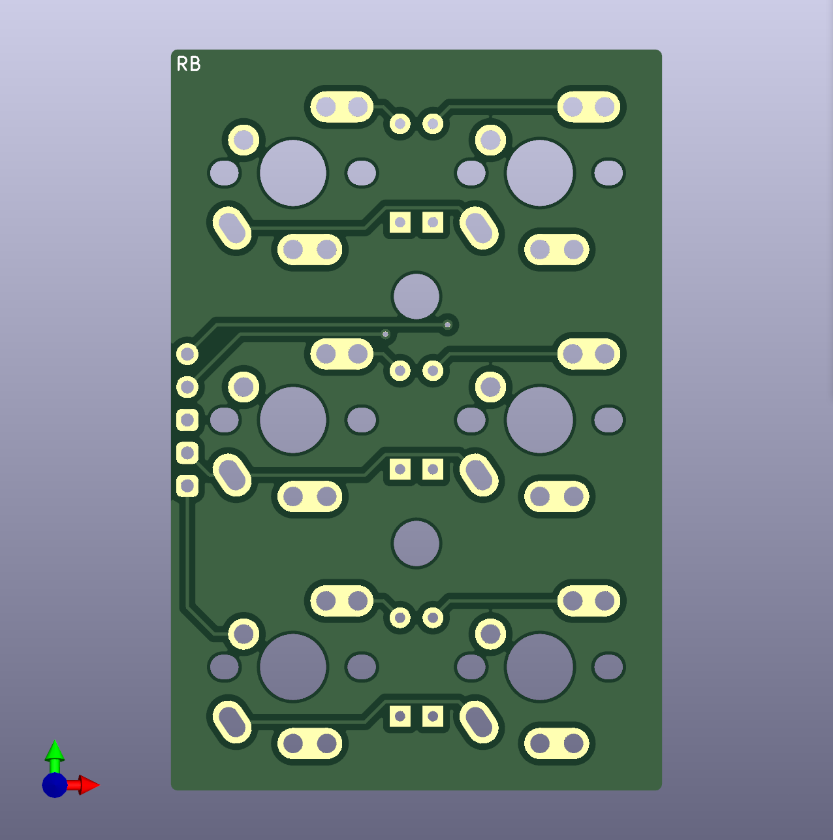
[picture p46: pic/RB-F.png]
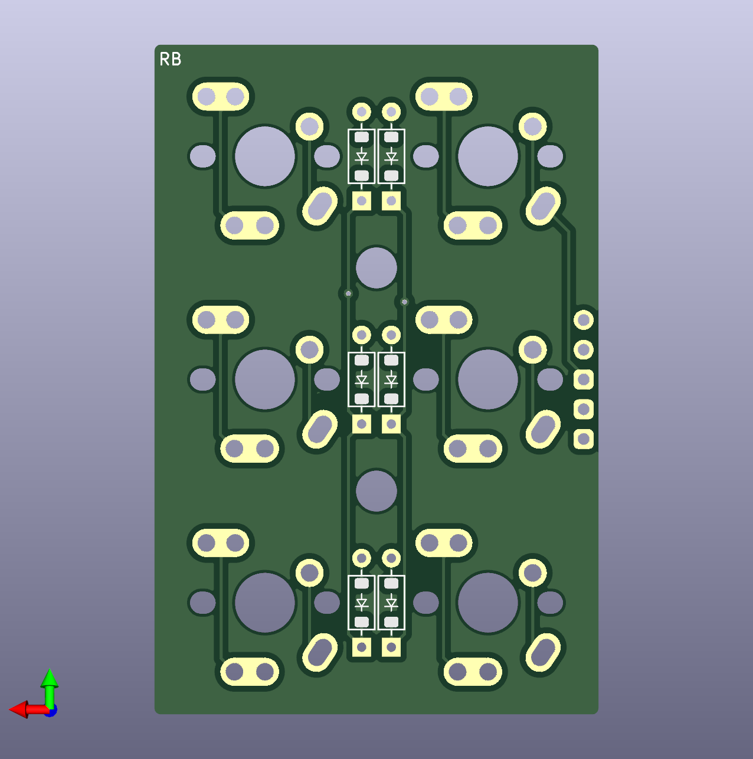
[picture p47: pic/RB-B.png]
|B part|||
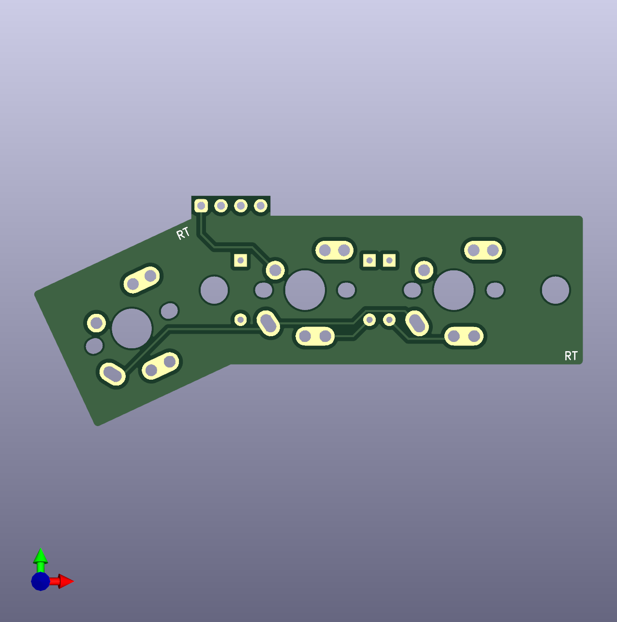
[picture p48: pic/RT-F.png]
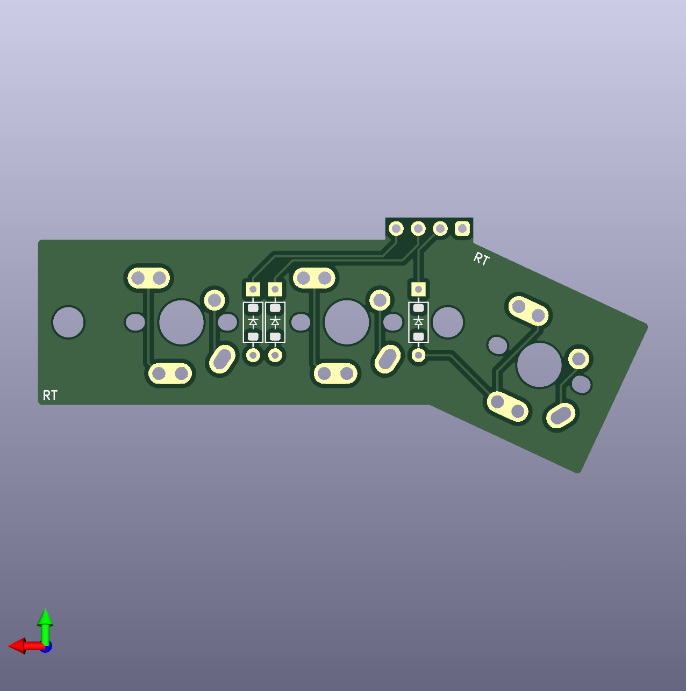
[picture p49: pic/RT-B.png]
|Thumb|||

### C、中央（手拉線拓展板）

|部件|正面（Front Side）|背面（Back Side）|
| -- | -- | -- |
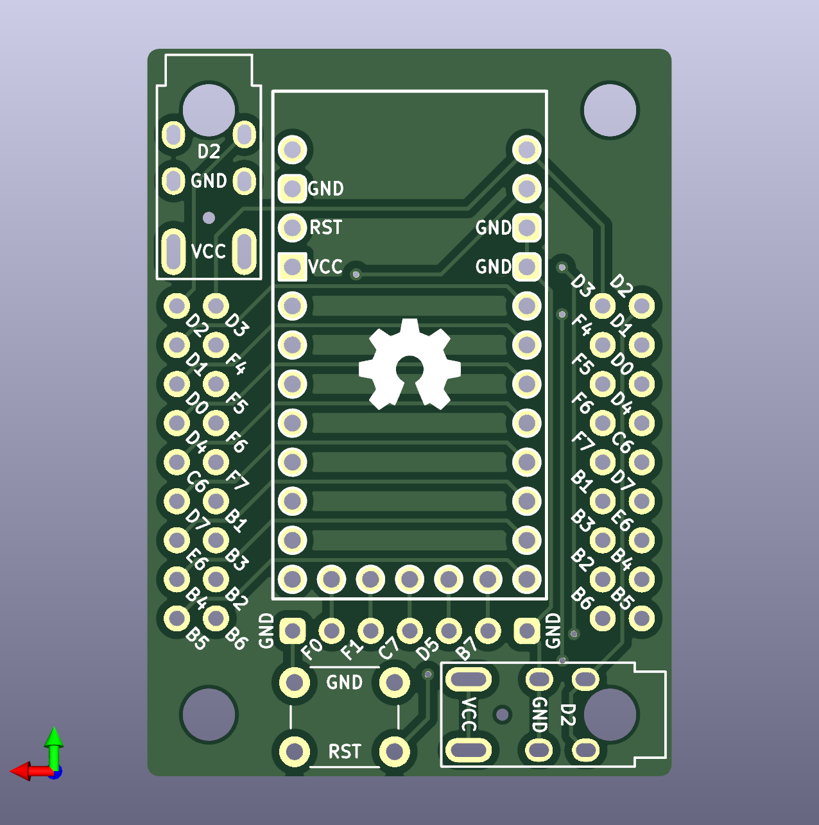
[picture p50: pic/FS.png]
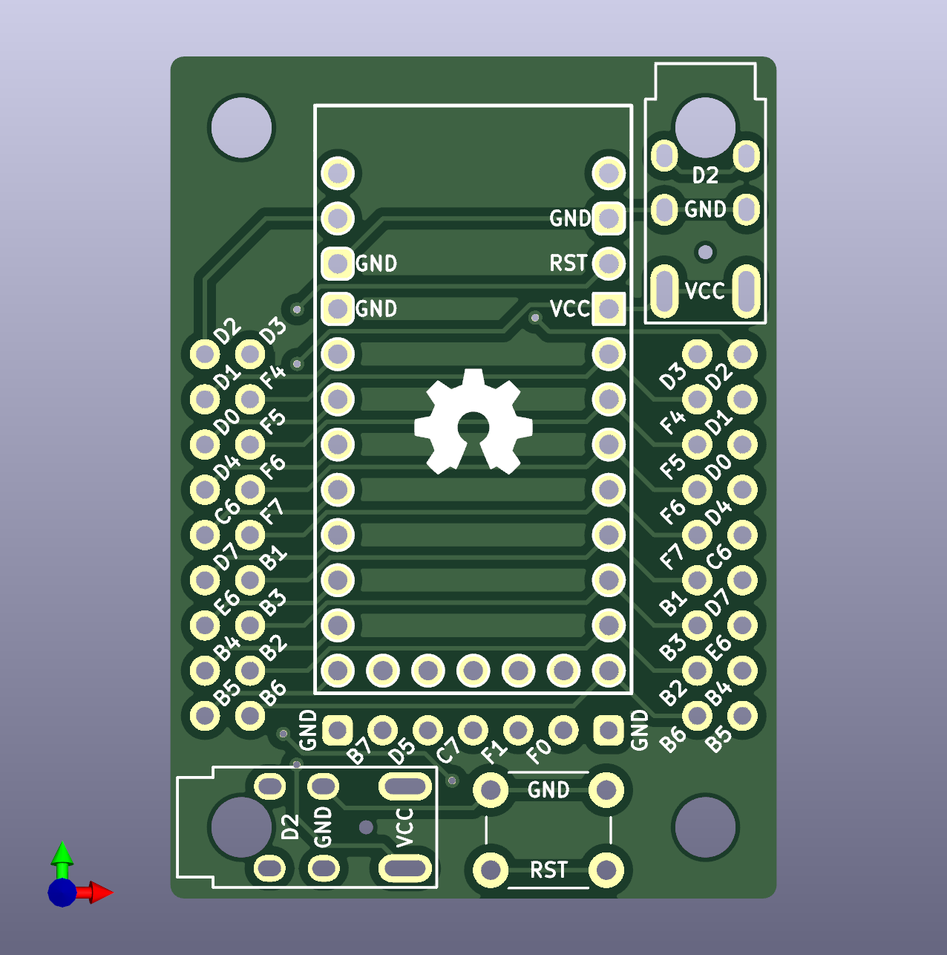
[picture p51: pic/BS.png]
|[HWMB](https://github.com/DreaM117er/Handwiring-Microboard)|||

### D、電路板實體

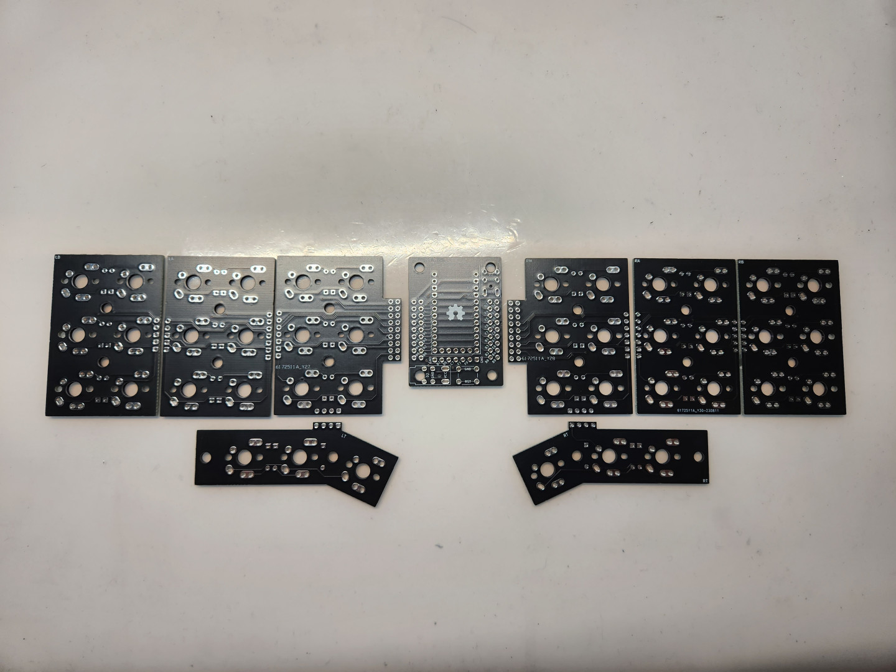
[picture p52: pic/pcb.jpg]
|視圖|  |
| -- | -- |

## （三）定位板及底板

> **Warning**
>
> 定位板及底板建議選用`玻璃纖維（FR4）`或`碳纖維（CF）`等相對韌性及硬度較`高`的材質製作，厚度建議為`1.5mm`或`1.6mm`。

> **Warning**
>
> 如果要使用`碳纖維（CF）`作為矮軸版本的外殼材料，請做好絕緣處理再進行安裝。

### A、定位板

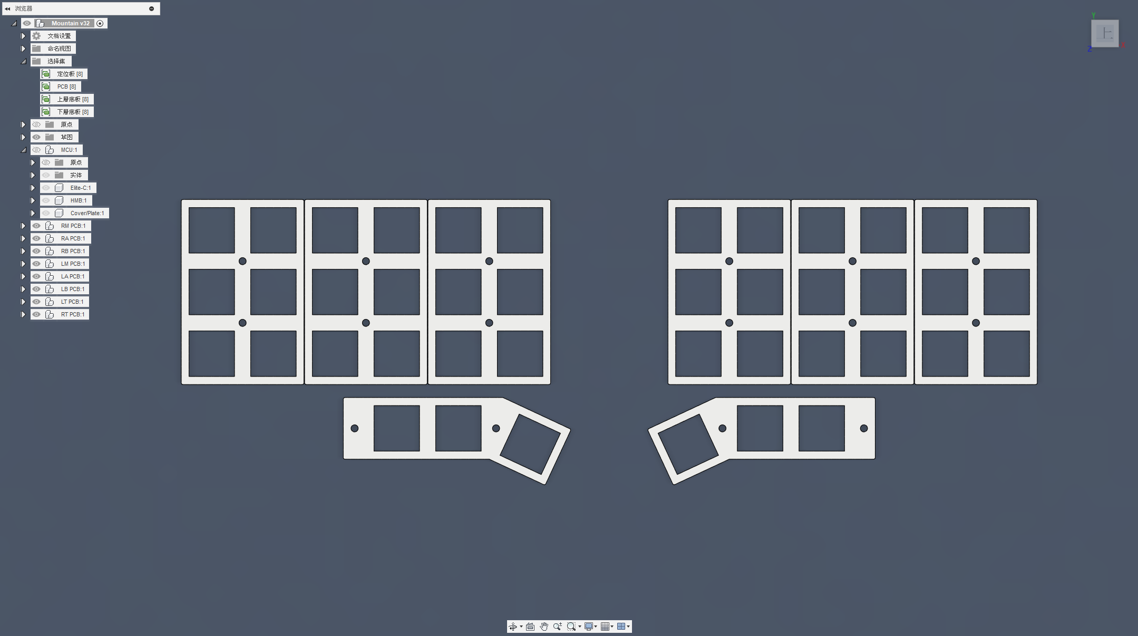
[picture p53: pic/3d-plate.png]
|3D視圖|  |
| -- | -- |
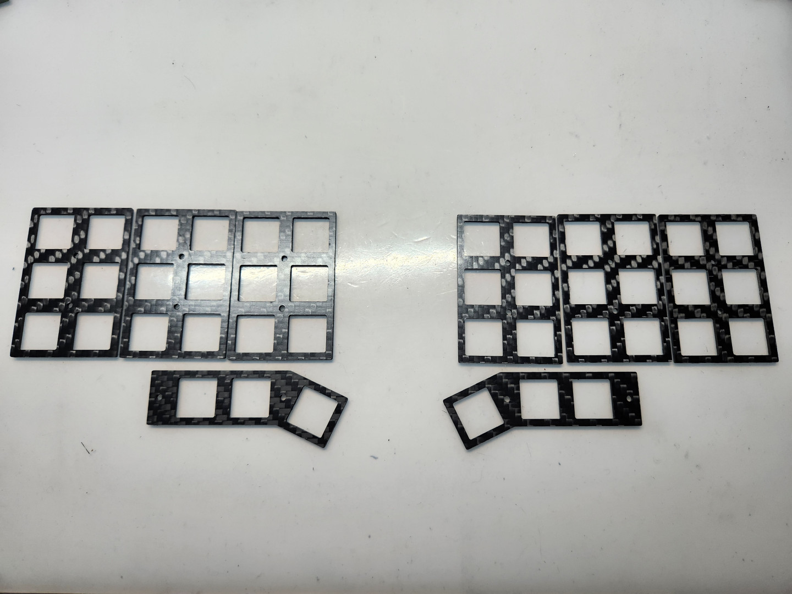
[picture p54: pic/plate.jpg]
| 實體 |  | 

### B、上層底板（A）及中央

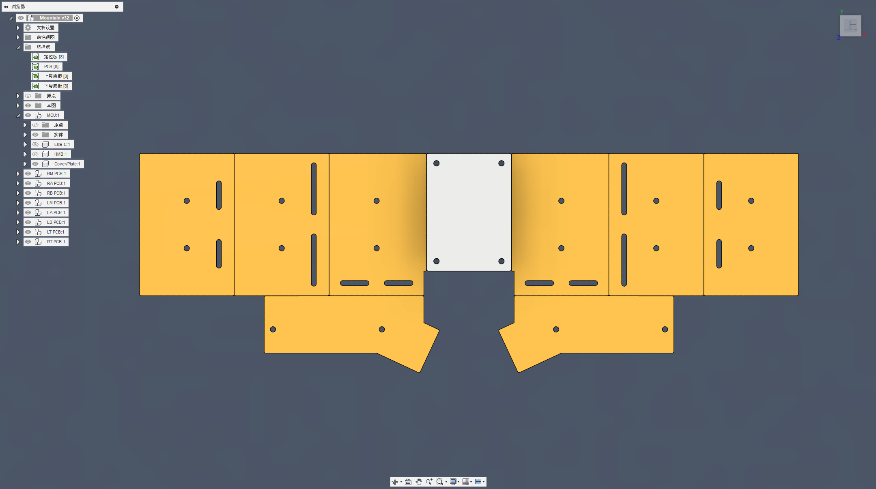
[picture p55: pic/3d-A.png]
|3D視圖|  |
| -- | -- |
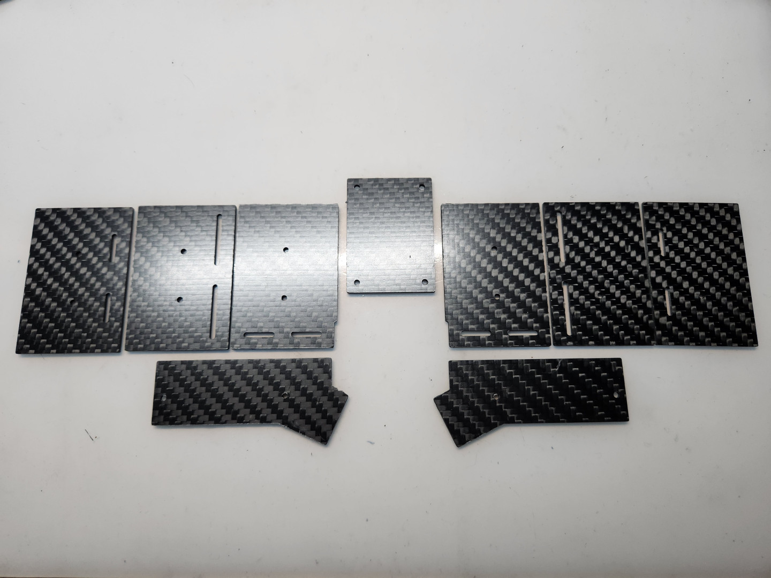
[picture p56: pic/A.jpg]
| 實體 |  | 

### C、下層底板（B）及中央

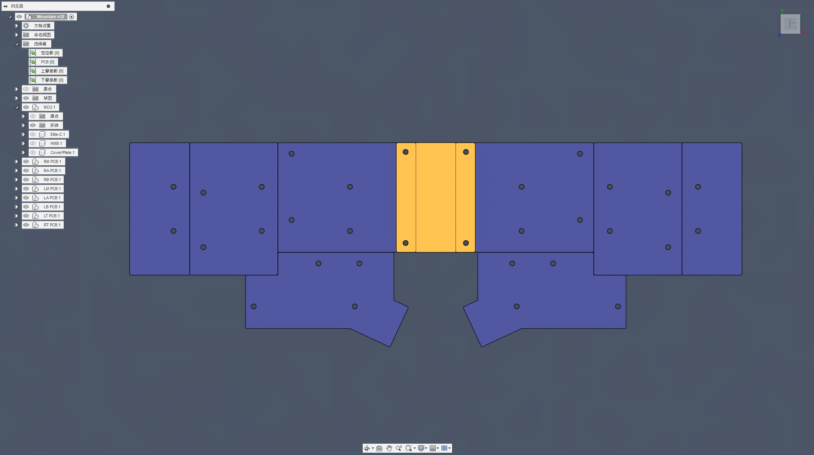
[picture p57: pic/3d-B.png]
|3D視圖|  |
| -- | -- |
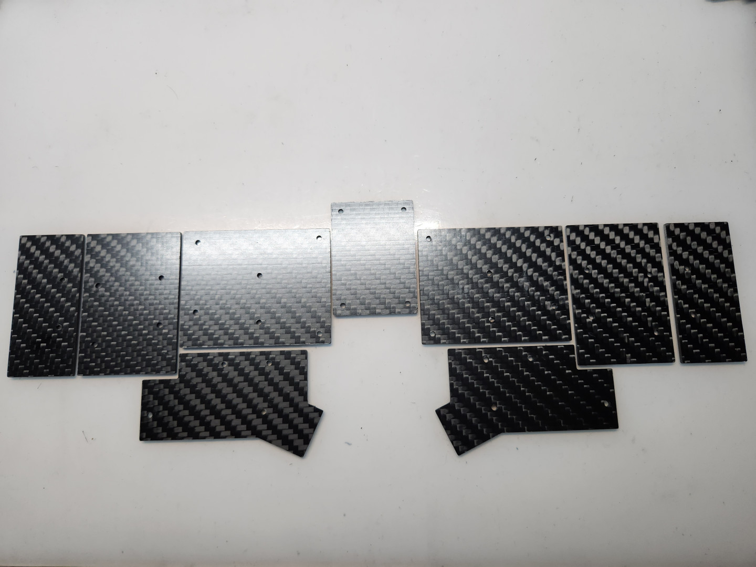
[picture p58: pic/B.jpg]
| 實體 |  | 

## （四）組裝開始

### A、拓展板、MCU及韌體

- 首先將手拉線拓展板及MCU主控板準備好。拓展板上面有將`VCC`、`RST`、`GND`等腳位標示出來，請對照MCU`背面`進行焊接安裝。

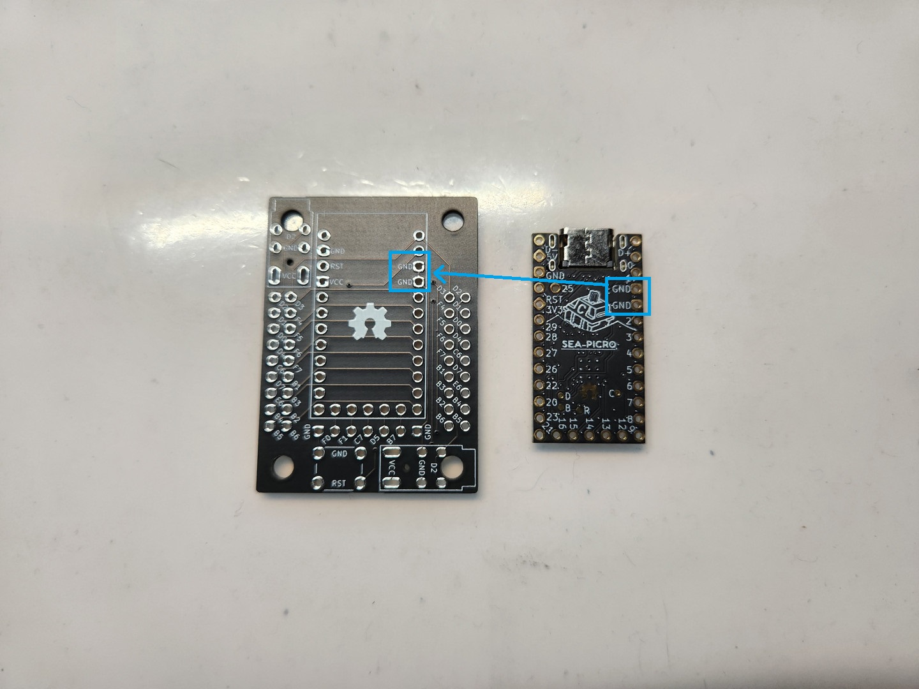
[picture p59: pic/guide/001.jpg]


- 接著將排針切至需要的大小，MCU的話會需要使用到`12pin`、`9pin`及`5pin`；公母排針請自行斟酌使用。

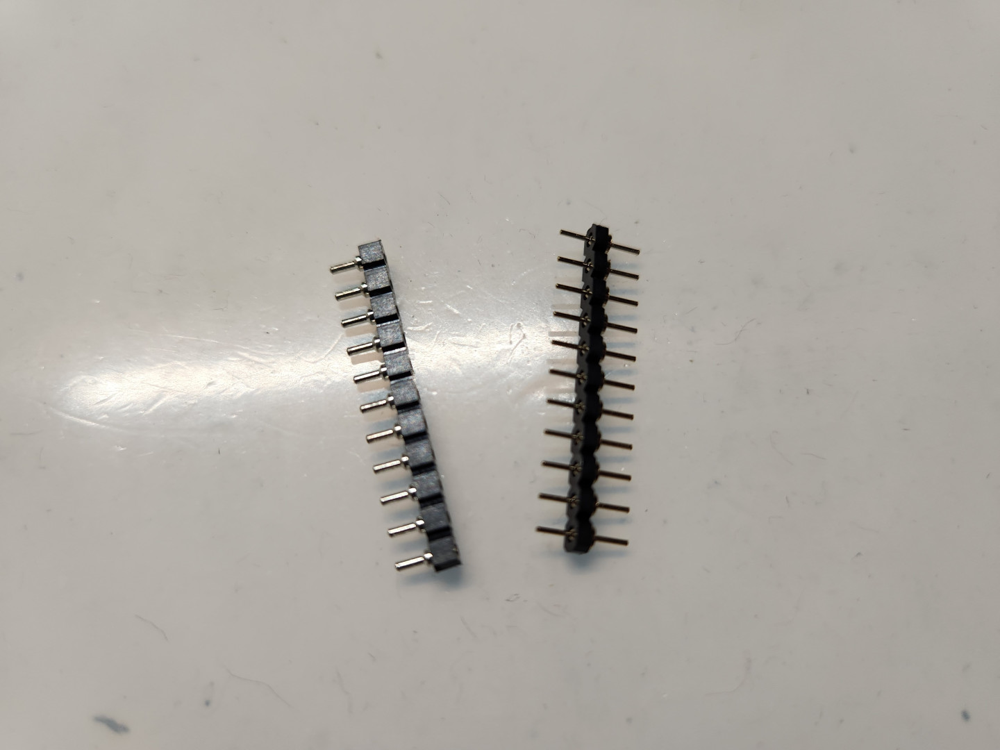
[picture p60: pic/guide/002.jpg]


- 這裡先將母排針安裝到拓展板，簡單固定好位置後進行焊接。

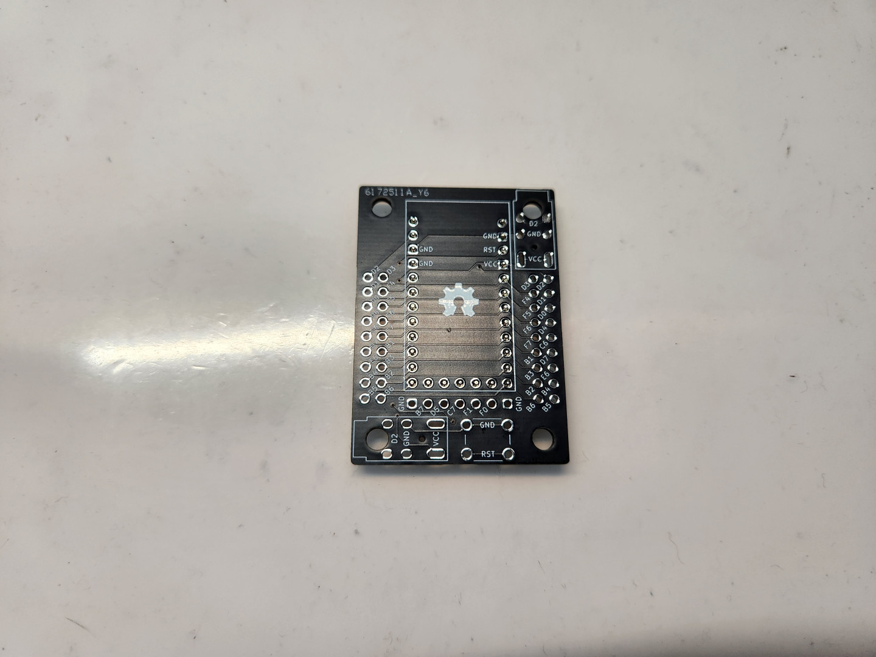
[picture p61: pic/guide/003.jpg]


- 這裡先將排針的頭尾部分先焊接固定上去，避免歪斜的情況發生。

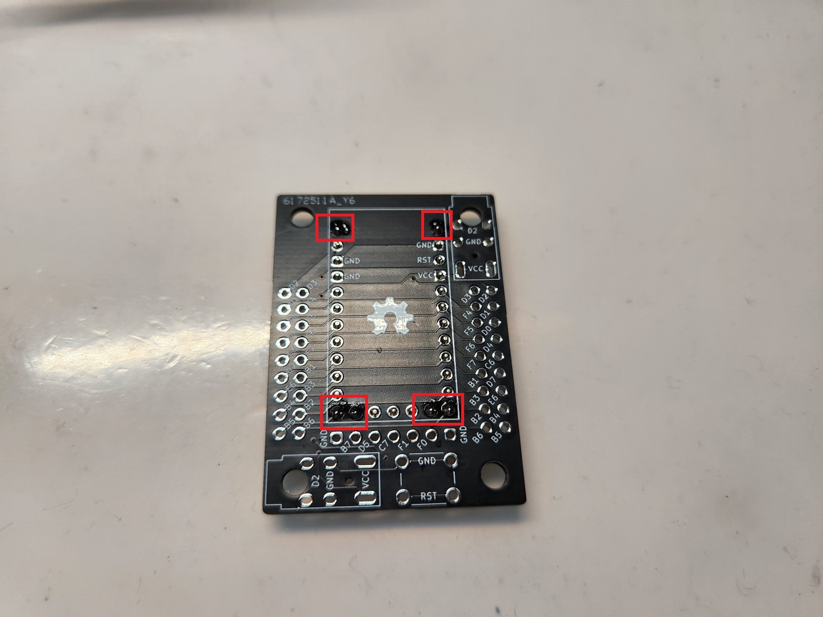
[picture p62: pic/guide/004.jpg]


- 焊接完會是這樣。

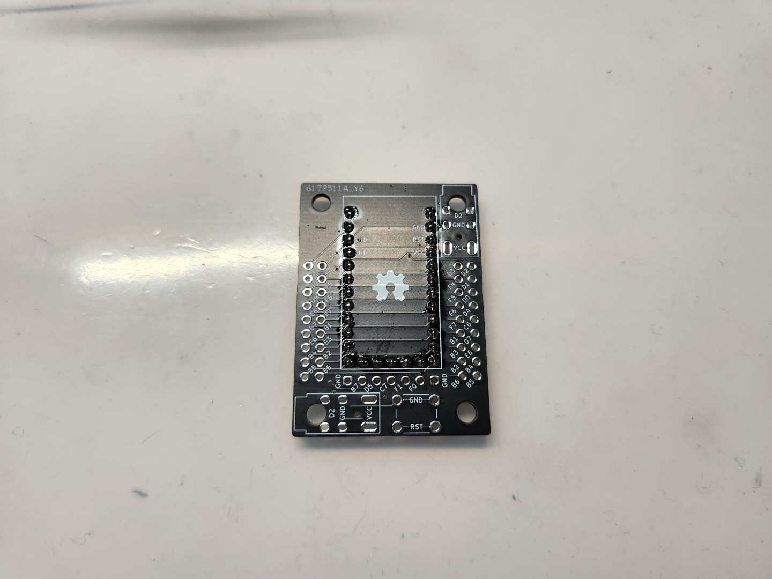
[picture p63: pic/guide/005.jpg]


- 接著將公排針安裝到拓展板上的母排針上。

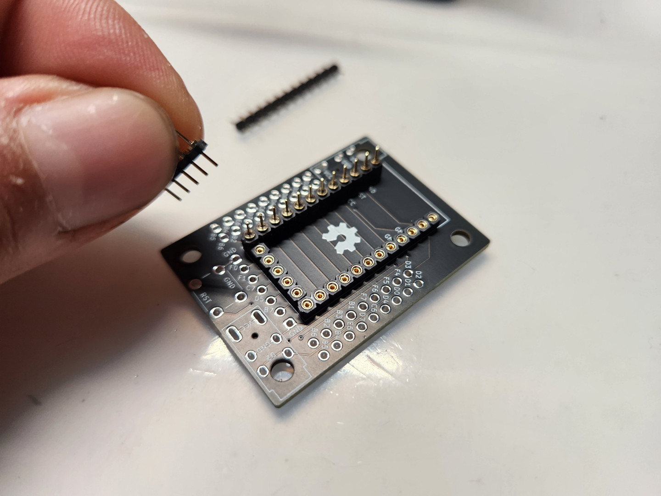
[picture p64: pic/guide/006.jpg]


- 然後將MCU對好腳位放上去定位，接著進行焊接。

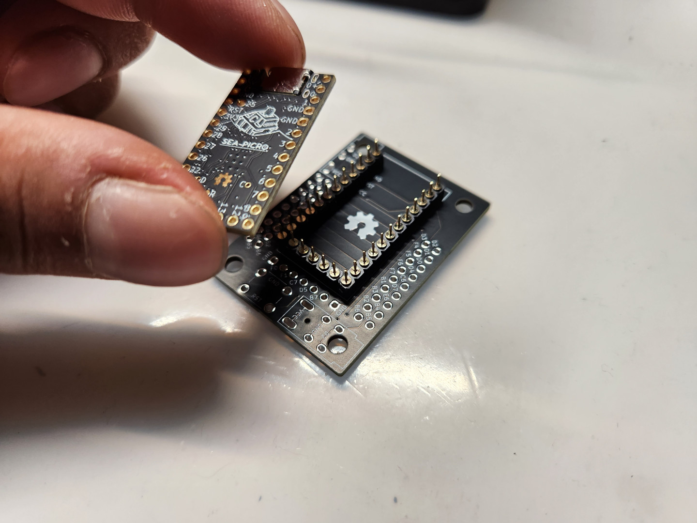
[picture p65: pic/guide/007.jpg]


- 這樣就將MCU固定好了。

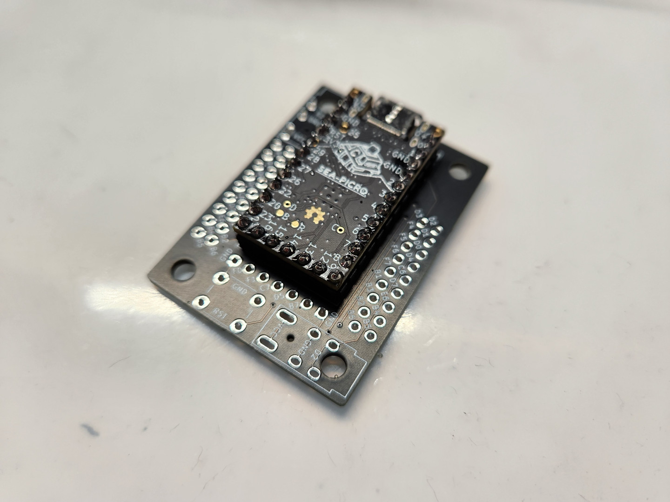
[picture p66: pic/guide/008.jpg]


- 再來將輕觸開關安裝到拓展板上。

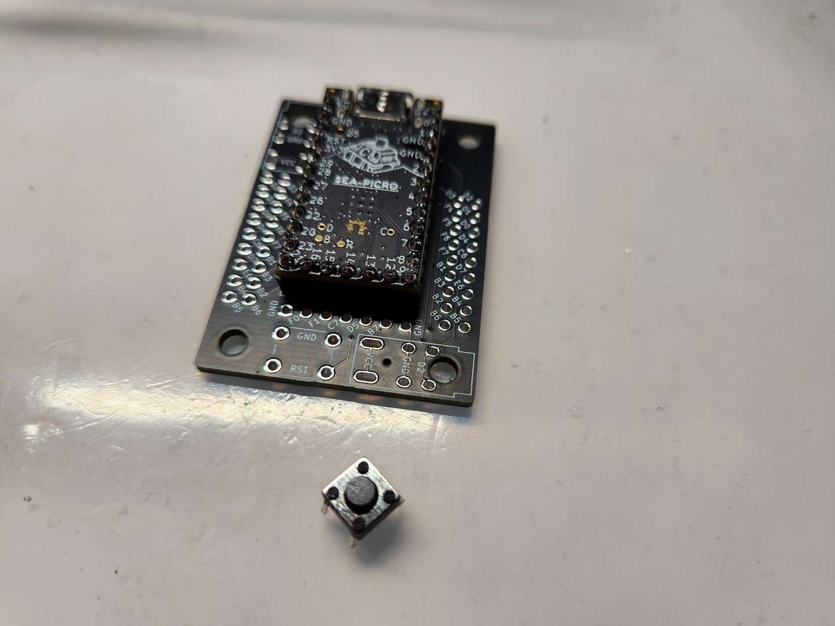
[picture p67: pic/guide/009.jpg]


- MCU的部分就完成安裝了。

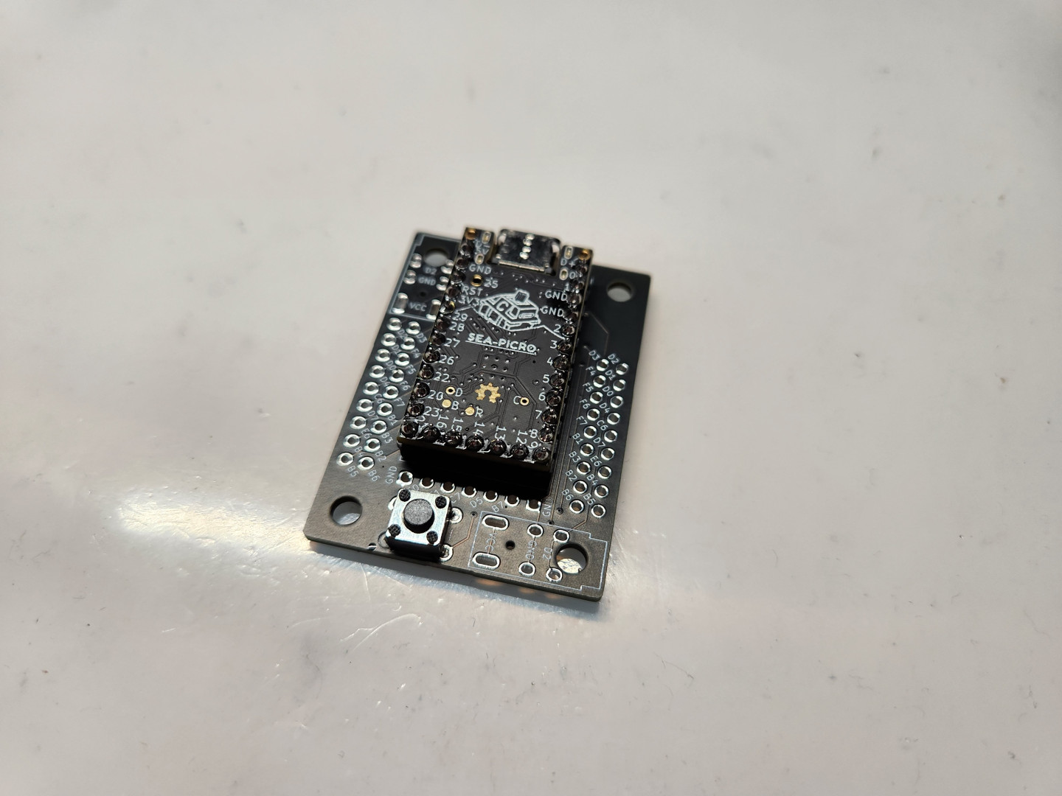
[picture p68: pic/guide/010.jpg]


- 接著將MCU接上電腦進行韌體的燒錄，由於現階段開源分離式鍵盤韌體的燒錄方式主流有2種，這裡會簡單的將做法寫下來讓大家參考：

> **Note**
>
> `ATMega32U4`：使用`QMK Toolbox`、`Auto-Flash`的方式進行韌體燒錄，韌體檔案為`.hex`。

> **Note**
>
> `RP2040`：同時作用`Reset`及`Bootloader`雙開關進行韌體燒錄，韌體檔案為`.uf2`。

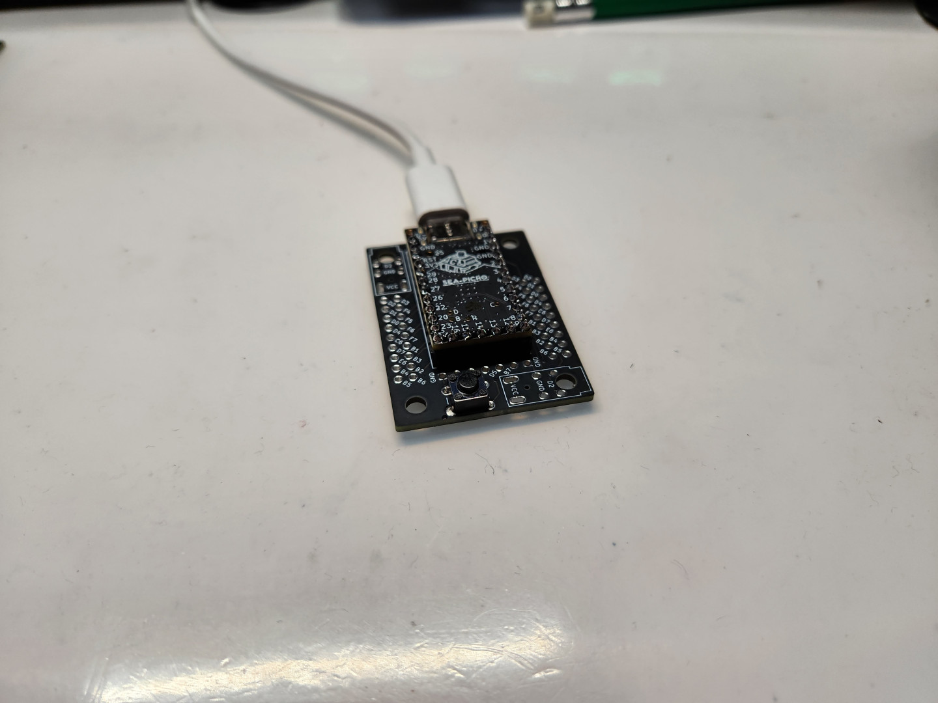
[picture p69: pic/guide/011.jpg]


- 根據個人使用的MCU類型且燒錄完畢後，打開`VIAL`確認鍵盤有沒有被讀取到。

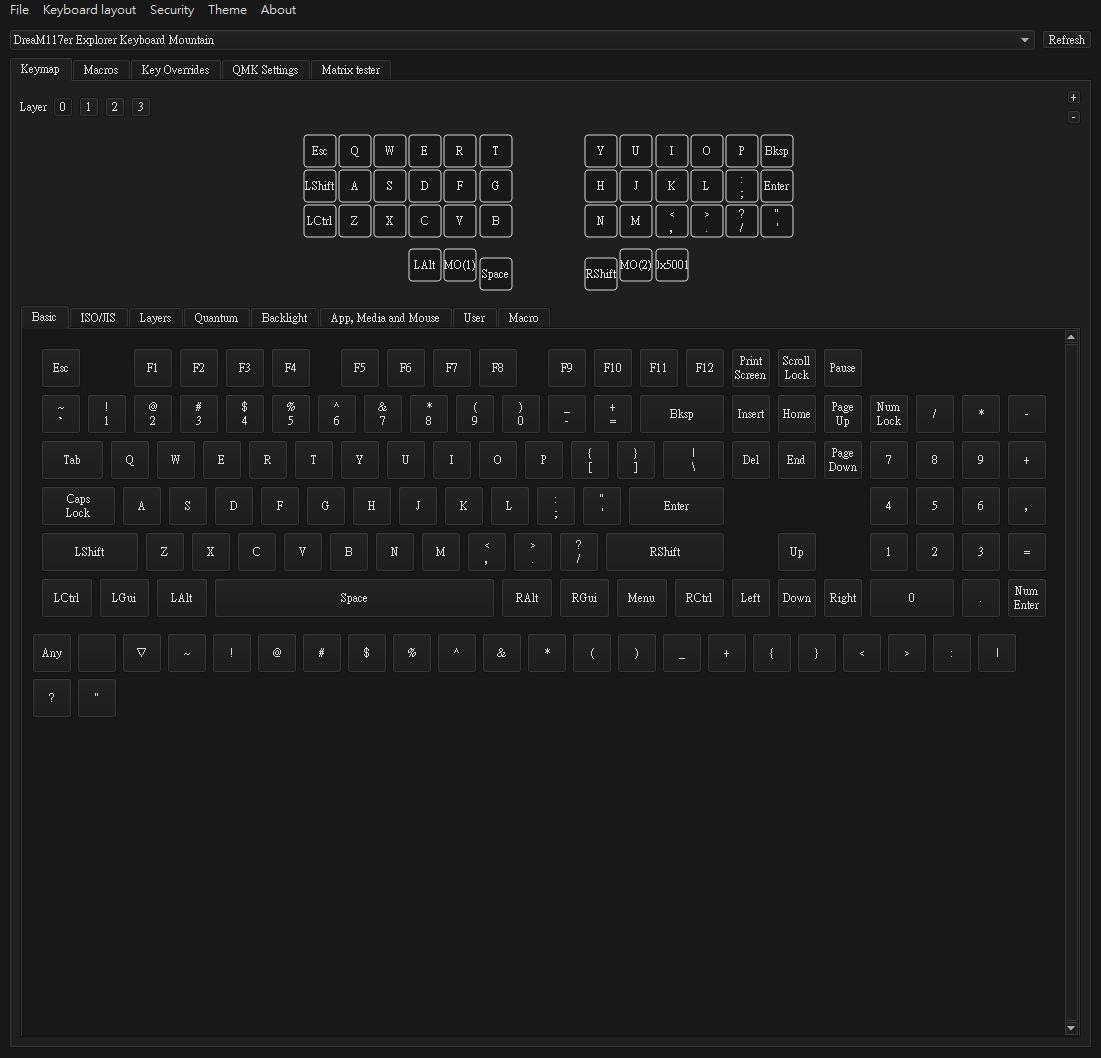
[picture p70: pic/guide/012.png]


- 確認沒有問題後，準備好`9pin`的公排針4組，焊接固定`RM`及`LM`電路板上的雙排排針。

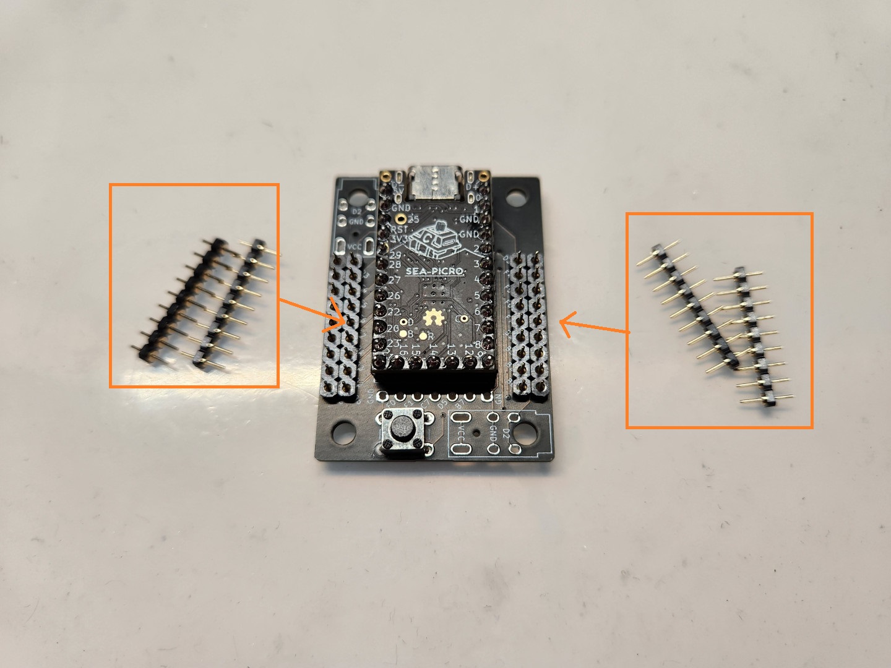
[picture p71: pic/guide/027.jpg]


- 公排針有圓形金屬墊片的部分`朝下`對著PCB安裝，完成固定之後將主控板暫時放在一邊，待會再來安裝

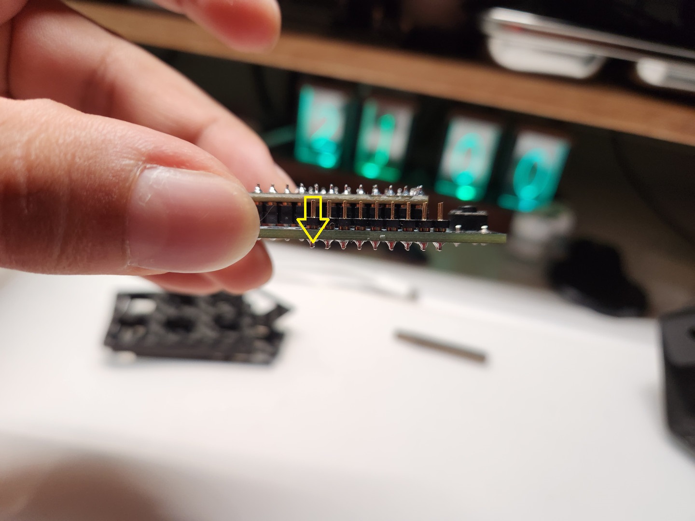
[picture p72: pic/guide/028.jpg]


### B、二極體

- 探索者2號早期設計的PCB只能支援`SOD-123`封裝的貼片式二極體，新設計的版本同時支援`直插式`及`貼片式`，這裡就看手邊有什麼類型的二極體擇一做選擇即可。

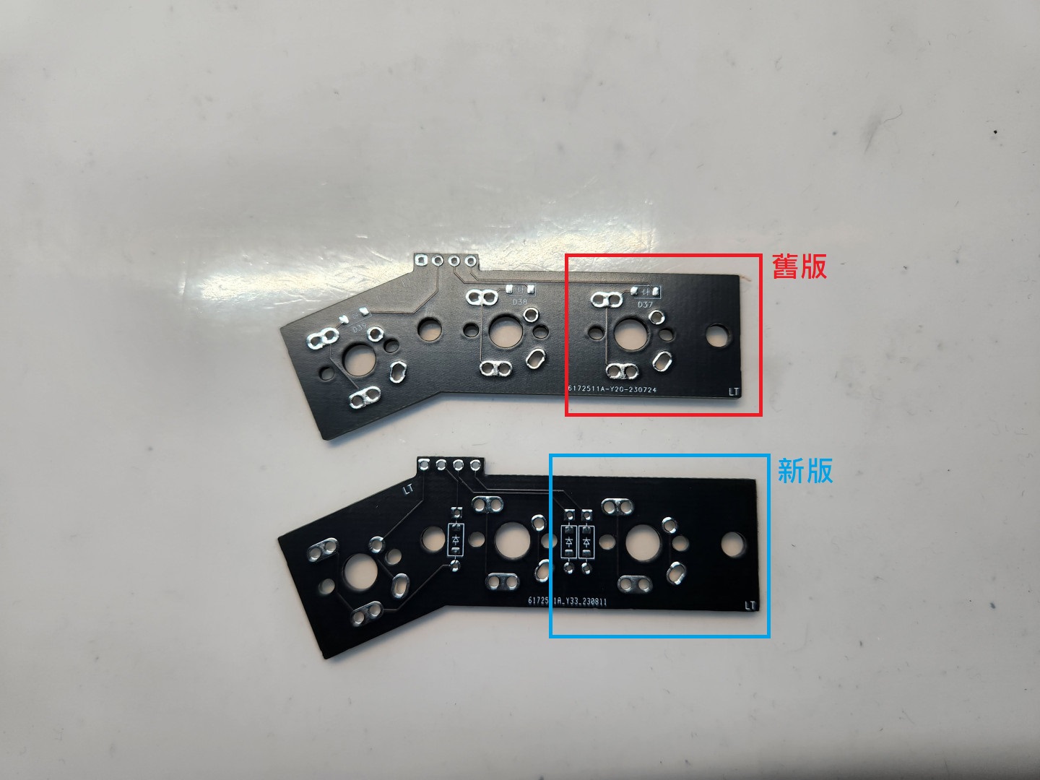
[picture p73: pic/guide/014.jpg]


#### a、貼片式

- 貼片式`1N4148`二極體紅色圈起來的部分為負極，也是PCB上標示的`箭頭方向`。




- 在PCB上二極體其中一邊的焊盤點上錫。



- 接上二極體的其中一邊做固定。



- 固定好二極體的一邊後，再將另一把也點上錫就完成了。



#### b、直插式

- 直插式`1N4148`二極體的黑色端點部分為負極，也是PCB上標示的`箭頭方向`。



- 將其中一端用工具彎曲先固定好長度



- 再將另一端也彎曲。



- 接著將兩邊用焊錫做固定。



- 固定完畢後將背面多餘長度的絲線剪斷即可。



- 接著把8張PCB的二極體都固定上去後，進行下一步。



- 接著將`9pin`的母排針安裝在`RM`及`LM`電路板的`正面`。



- 焊接完成後接著進行下一步。



### C、滑動軌道、底板及銅柱

#### a、滑動軌道

- 這是所有底板的示意圖，首先將其中一片中央的`cover`板暫時放在一邊，它會最後進行安裝。



- 接著準備好`M2x6mm的平頭螺絲`、`M2六角螺母`、`防滑墊片`及`橡膠墊圈`，先將滑動軌道安裝完成。



- 首先將`M2x6mm平頭螺絲`墊在`B底板`的軌道定位螺絲孔下方。



- 再將有2個滑動軌道的`A底板`暫放在2顆定位螺絲上方。



- 接著將`防滑墊片`放在螺絲上。



- 再放上`橡膠墊圈`。



- 然後將`M2六角螺母`固定在螺絲上面，2邊螺絲`簡單鎖緊`即可，並且測試一下滑動軌道的運作順暢度。



- 接著將所有的滑動軌道都安裝完畢。



#### b、銅柱

> **Note**
>
> 接著要來安裝銅柱，請依照使用的鍵軸類型選擇相對應高度的銅柱規格。

| |銅柱規格|數量|備註|
| -- | -- | -- | -- |
|Choc、LP矮軸|`7mm`|12個|主鍵區用|
|Choc、LP矮軸|`5mm`|4個|拇指區|
|MX軸|`10mm`|12個|主鍵區用|
|MX軸|`7mm`|4個|拇指區|
|中央區域|`14mm`|4個|-|

- 接著就依照上述表格將銅柱準備好，在安裝固定好滑動軌道後，剩下的螺絲孔都是安裝銅柱的，請使用`M2x5mm`的螺絲進行安裝。



- 完成左右邊底板後，再將中央`cover`底板及`14mm銅柱`安裝上去。



- 這樣底板就安裝好了。



- 接著進行滑動軌道測試，請將它拿起來直接挪移。





- 確認沒有問題後，底板翻至背面即可將`自黏腳貼`貼上，建議粘貼位置為`滑動軌道正下方`及`邊緣區域`。



### D、PCB連接及鍵軸安裝固定

- 接著準備好`28AWG矽膠電線`，將PCB按照`最大位移的配列`擺放。



- 接著量測`可位移最大量長度`的電線，將它剪下來，這裡合計要剪下`32段`。



- 再來將電線的頭尾線頭剝出來。



- 大致上是這樣，接著準備好`烙鐵工作台`跟`鑷子`，這裡會需要用它來固定PCB，要將電線接上去。 



- 首先將PCB正面朝上放置，在PCB邊緣處的`4pin`、`5pin`、`7pin`上先點一些焊錫，這裡我們要從PCB的`下方`接線上去。



- 完成接線後，稍微將正面多餘的焊錫用電烙鐵抹掉。



- 這裡會建議先焊接固定單片PCB，這樣接線比較容易。



- 這是PCB之間連接完的樣子，都是從PCB的背面接線。



- 接著將單邊的PCB都連接在一起。



- 將PCB之間的連接線都焊接固定好之後，將左右手PCB暫時放在一邊。



> **Note**
>
> 這是探索者2號PCB可支援的鍵軸種類，請依自己的需求做鍵盤安裝。



- 接著將鍵軸固定到定位板上。



- 如果有需要增加夾心棉的話這時就要放上去了。



- 固定好鍵軸之後，將PCB從背面放上去定位。



- 定位好PCB後，將鍵軸的所有針腳都焊上。



- 將鍵軸都焊接固定好之後，將左右手`RM`、`LM`的電路板接在主控板上。



- 安裝左側。



- 接著安裝右側。



- 左右手都安裝好之後，將放在一旁的底板拿出來。



- 這裡會需要從`最外側往內側`做安裝固定，對好銅柱上的螺絲孔之後，就用`M2x4mm`的螺絲固定。





- 接著安裝固定中間。



- 接著中央左右側的`RM`及`LM`都固定好。



- 再拇指區用螺絲鎖上。



- 最後就可以把第二片cover用螺絲固定在主控板上。




- 這樣就完成了。



- 接著將鍵盤連接到電腦上測試按鍵。



- 確認鍵盤按鍵可正常運作之後，再將鍵帽安裝上機。



- 完成。



> **Note**
>
> 最後一步請將鍵盤接上電腦，直接進行滑動軌道測試，確認電路板下方的電線不會影響到滑動軌道上的螺帽。

## （五）操作方式

> **Note**
>
> 請將鍵盤平放在桌面上，將手自然擺放在鍵盤上，食指對好鍵盤上的盲鍵，並且微調滑動軌道到自己覺得最舒適的位置上即可開始使用鍵盤。




- MX版本及LP版本示意：



> **Note**
>
> 謝謝大家。

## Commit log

2023-07-26 update files
    [AA.step, AB.step, BA.step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]
2023-07-31 fix garber
    [RM-B_Cu.gbl, RM-B_Mask.gbs, RM-B_Paste.gbp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]
2023-08-03 update garber files
    [LA-B_Cu.gbl, LA-B_Mask.gbs, LA-B_Paste.gbp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]
2023-08-08 fix all things
    [AA.step, AB.step, BA.step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]
2023-08-10 re-design pcb
    [thumb-plate.step]
2023-08-10 update pcbs
    [LA-B_Cu.gbl, LA-B_Mask.gbs, LA-B_Paste.gbp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]
2023-08-14 update pcb files
    [LA-B_Cu.gbl, LA-B_Mask.gbs, LA-B_Paste.gbp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]
2023-08-16 update garber
    [LA-B_Cu.gbl, LA-B_Mask.gbs, LA-B_Paste.gbp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]
2023-08-22 fix plate for GLP
    [main-plate.step, thumb-plate.step]
2023-08-26 fixed RM's zones
    [RM-B_Cu.gbl, RM-B_Mask.gbs, RM-B_Paste.gbp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]
2023-09-25 update half-mountain readme&guide
2023-09-25 update link for half-mountain
